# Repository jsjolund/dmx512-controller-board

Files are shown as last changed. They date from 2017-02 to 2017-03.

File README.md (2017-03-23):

# Sunshine DMX512 Controller Board
Controller board for DMX512 compatible lighting fixtures, built around the ARM Cortex-M4 processor (STM32F411RET).

On the hardware side, there are of four PCB:s, a main board containing the microcontroller as well as DMX512, USB USART and power circuitry. Other boards contain buttons, LCD, potentiometer sliders and similar. See the Kicad project files for details.

The software is built using the STM32 hardware abstraction layer (HAL). Aside from hardware drivers for the various input devices, it contains DMX512 generation and a simple menu system for the LCD.

Enclosure

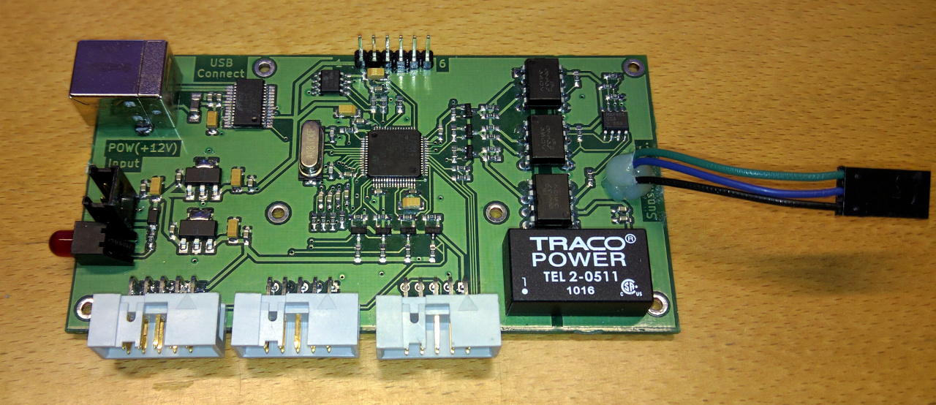
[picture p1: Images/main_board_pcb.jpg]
Main PCB


## STM32F411 docs
[Nucleo-64 board documentation](http://www.st.com/web/en/resource/technical/document/user_manual/DM00105823.pdf)

[STM32F411 Datasheet](http://www.st.com/resource/en/datasheet/stm32f411re.pdf)

[STM32F411 Reference Manual](http://www.st.com/resource/en/reference_manual/dm00119316.pdf)

[STM32F411 Programming Manual](http://www.st.com/resource/en/programming_manual/dm00046982.pdf)

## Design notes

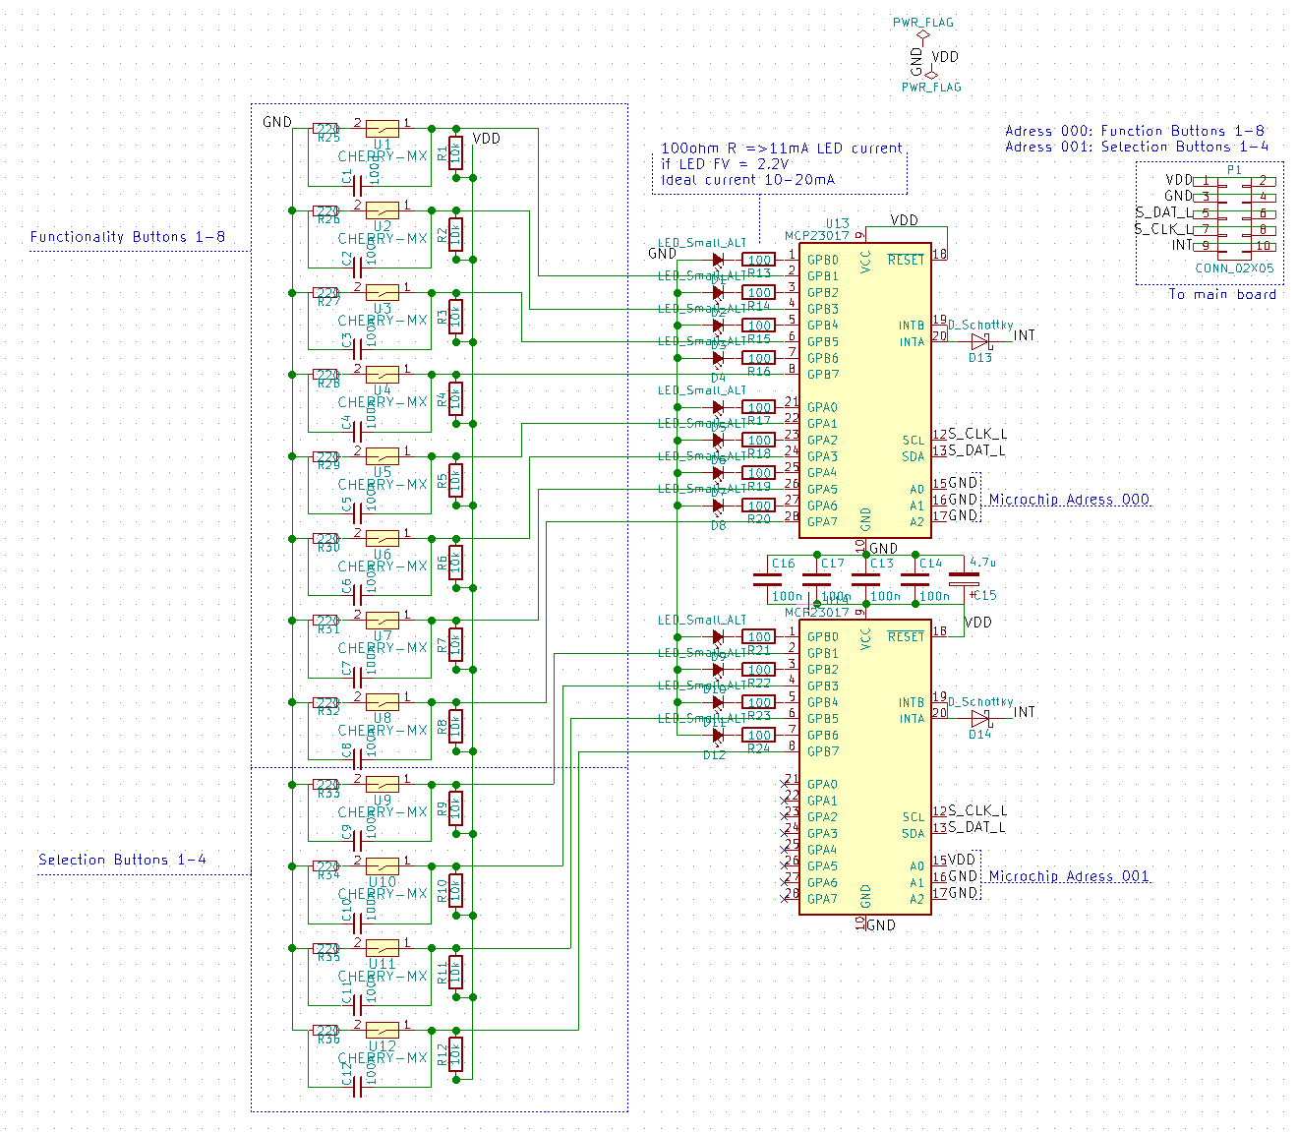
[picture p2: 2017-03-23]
Images/kicad_schematic_buttons.png

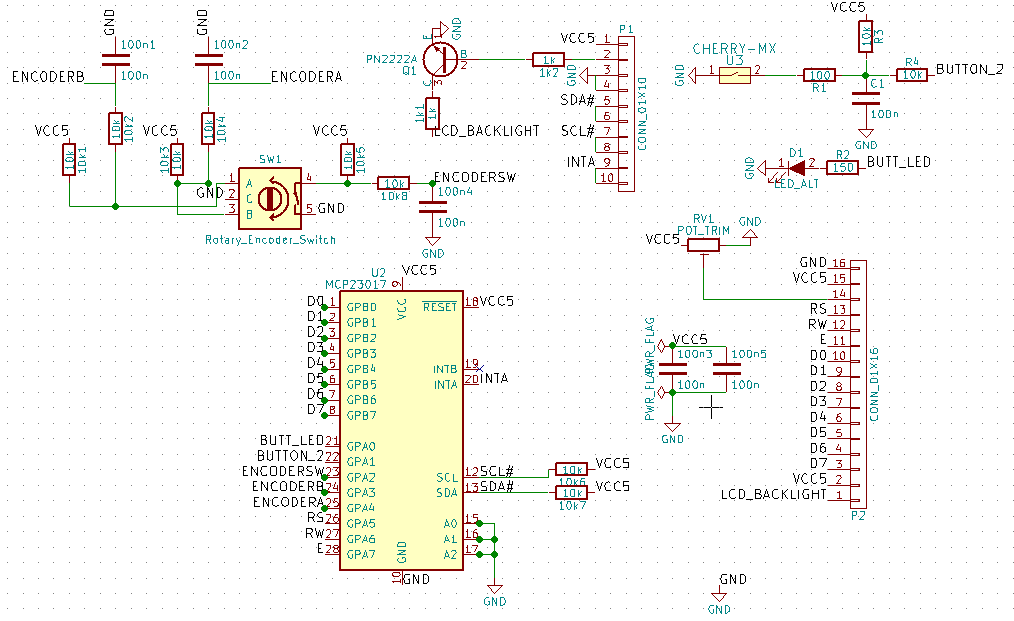
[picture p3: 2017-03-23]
Images/kicad_schematic_lcd.png

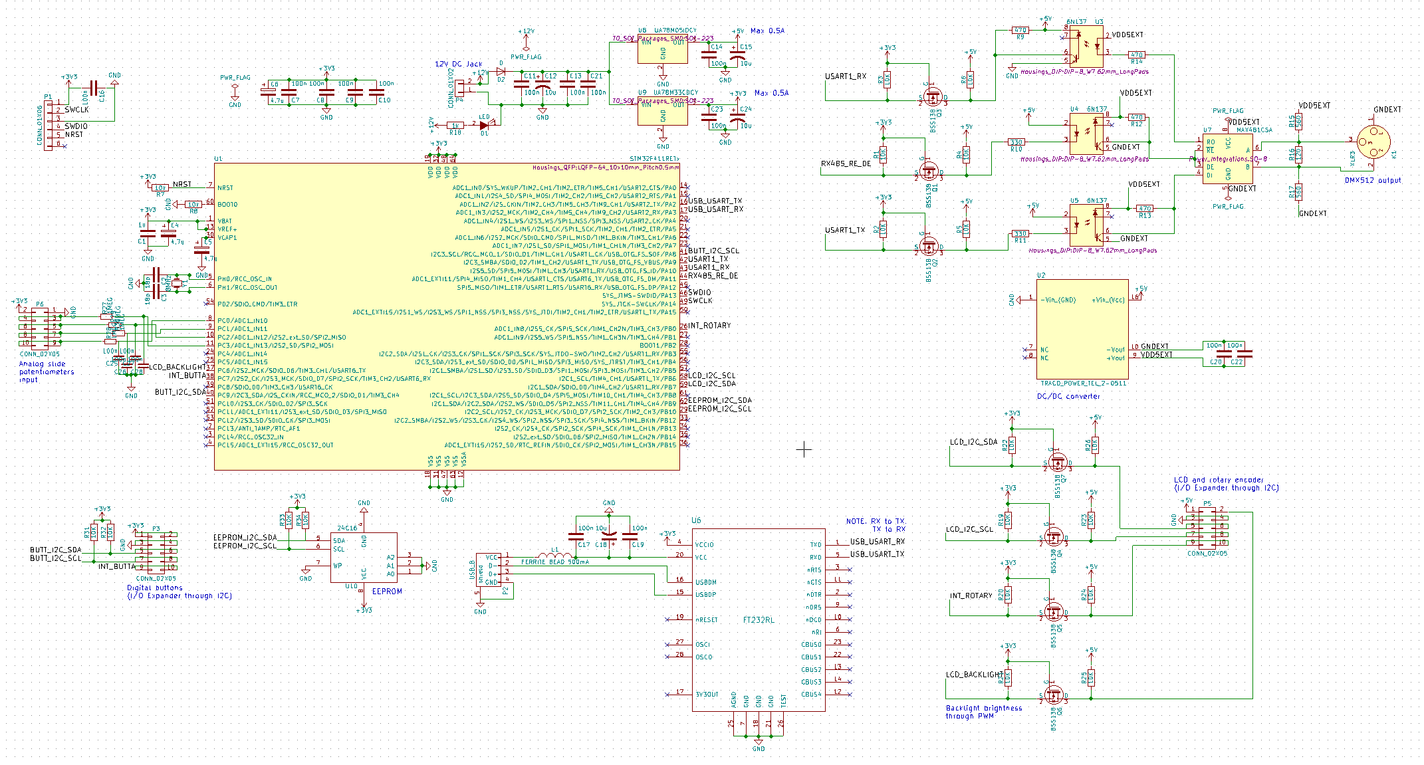
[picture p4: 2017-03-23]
Images/kicad_schematic_main.png

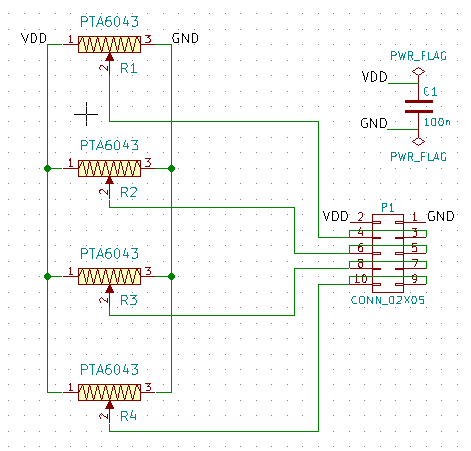
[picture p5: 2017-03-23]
Images/kicad_schematic_sliders.png

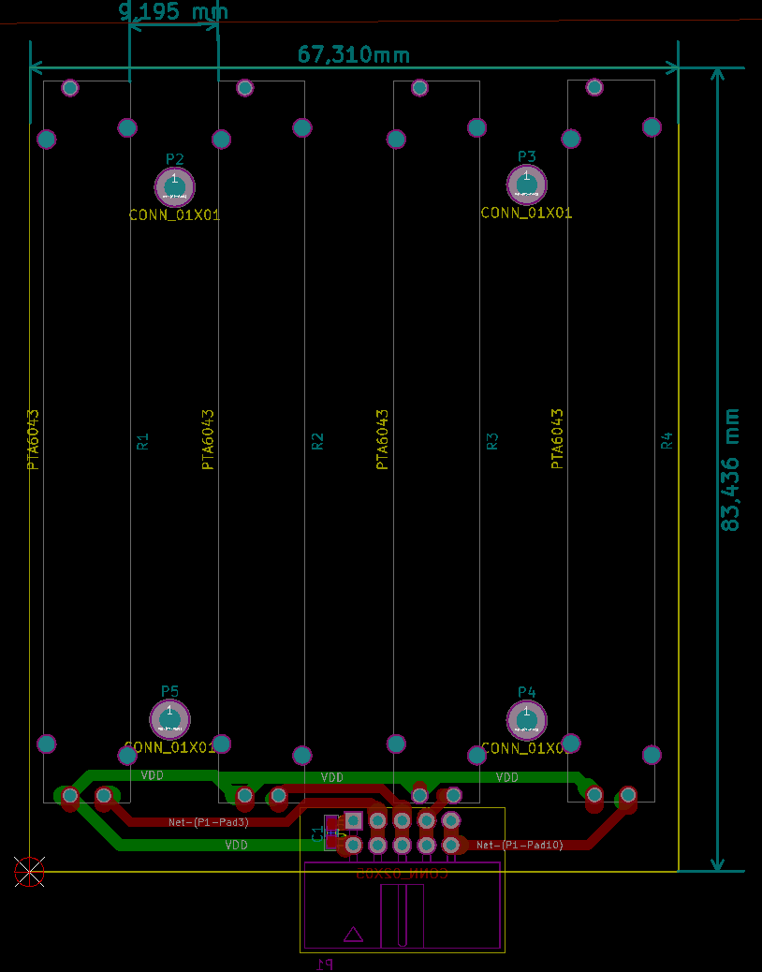
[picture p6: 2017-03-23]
Images/kicad_pcb_sliders.png

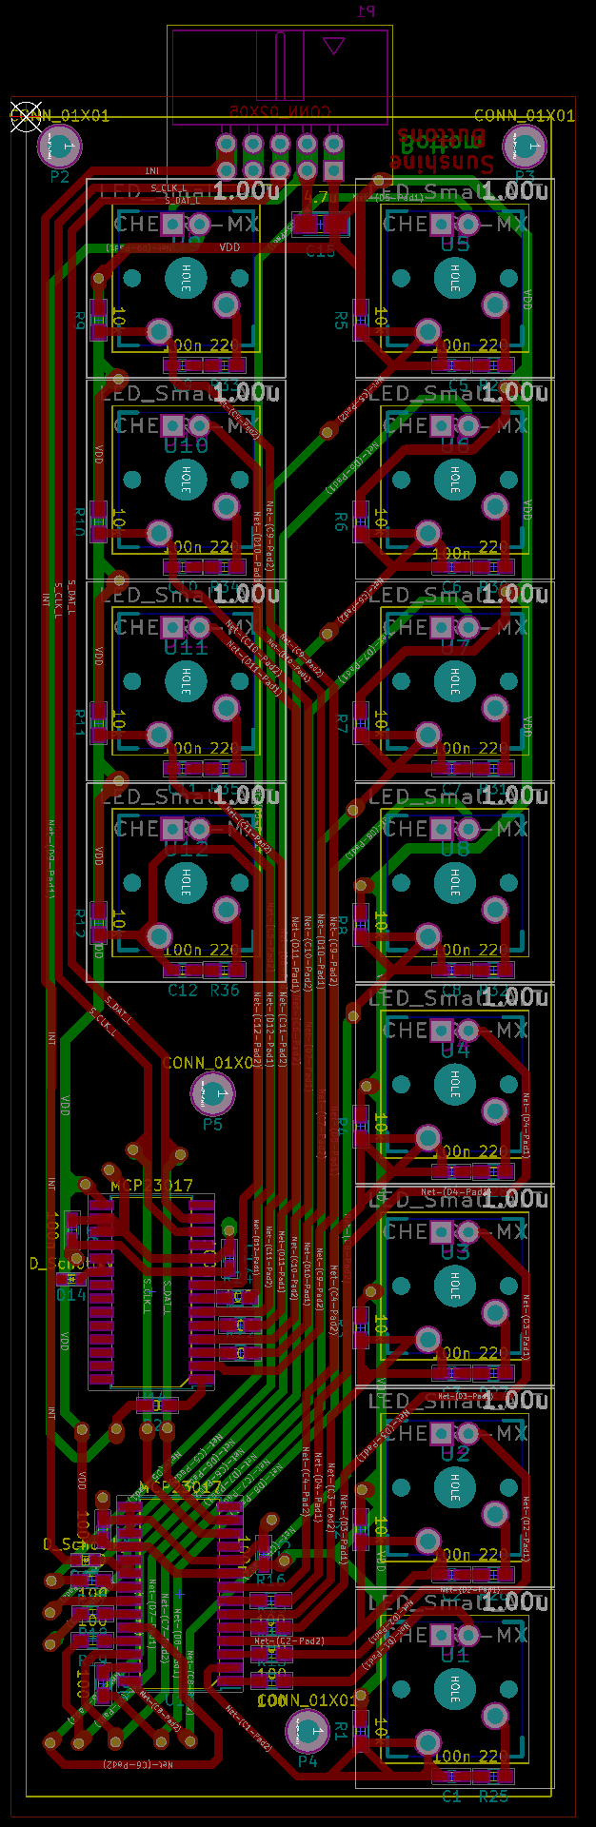
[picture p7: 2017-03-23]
Images/kicad_pcb_buttons.png

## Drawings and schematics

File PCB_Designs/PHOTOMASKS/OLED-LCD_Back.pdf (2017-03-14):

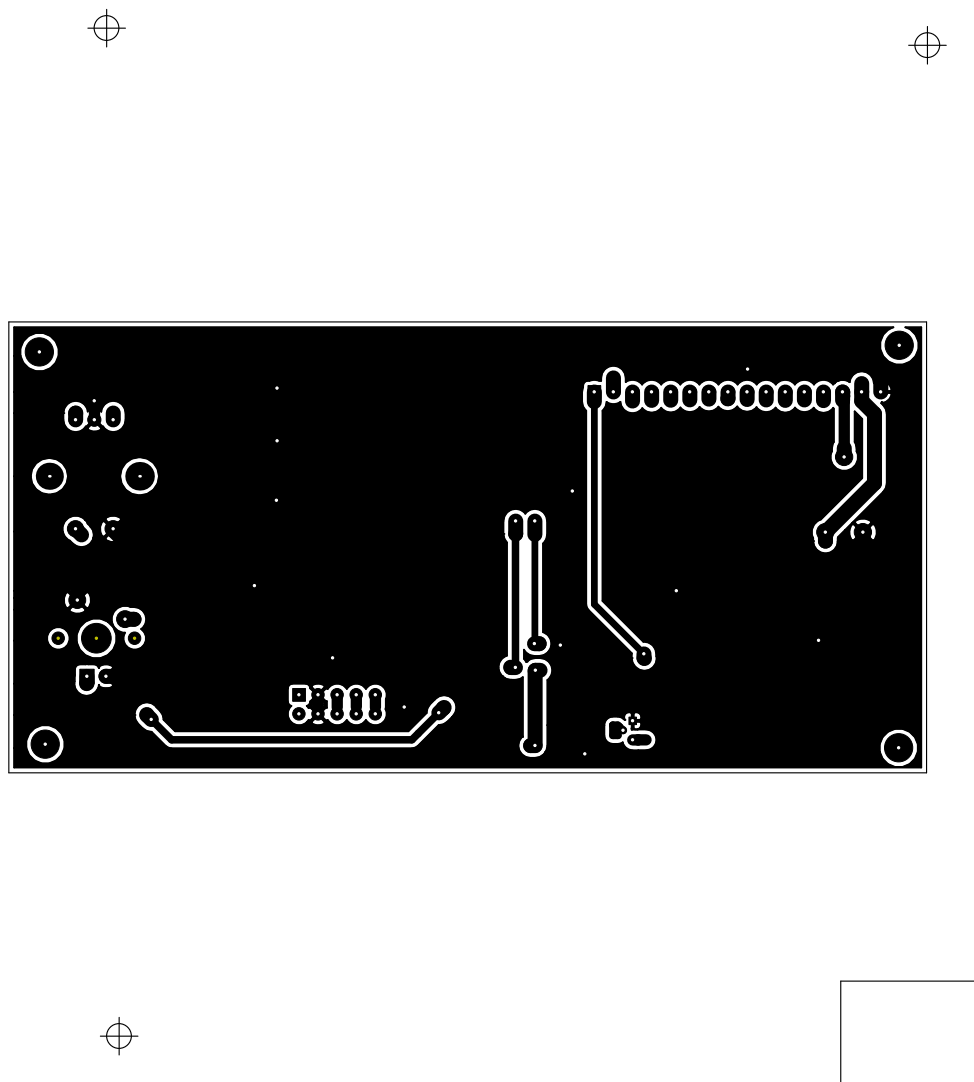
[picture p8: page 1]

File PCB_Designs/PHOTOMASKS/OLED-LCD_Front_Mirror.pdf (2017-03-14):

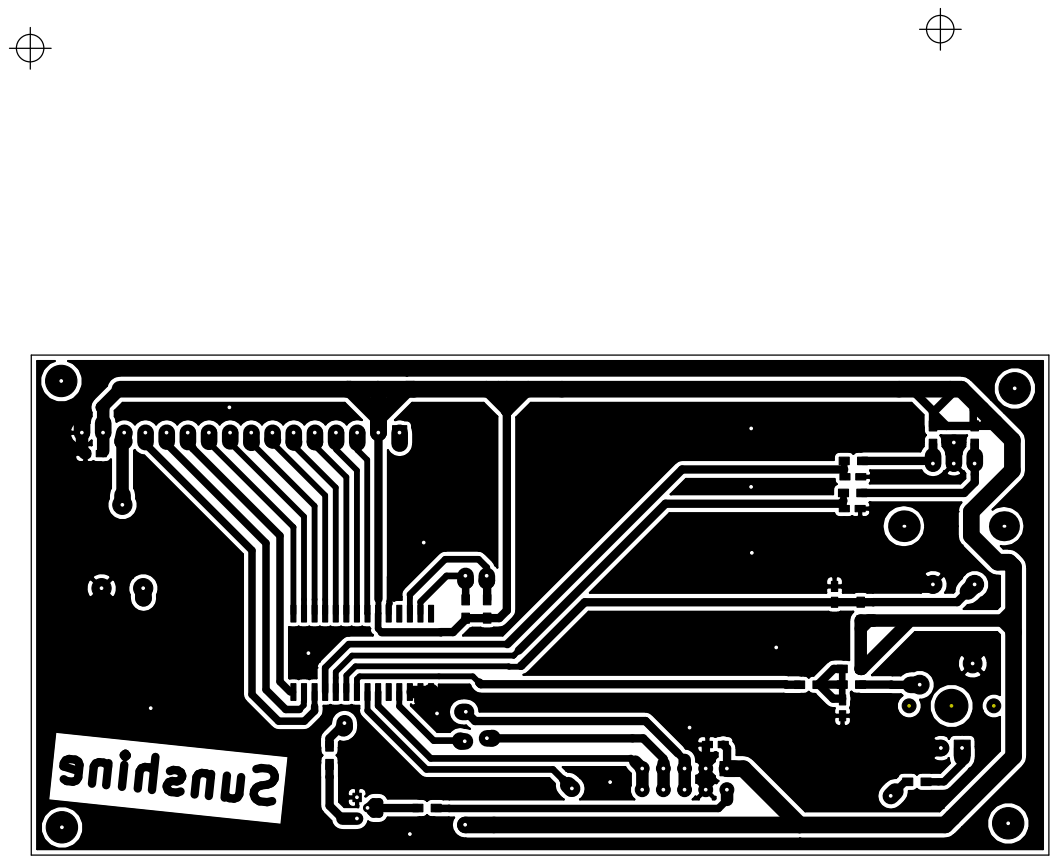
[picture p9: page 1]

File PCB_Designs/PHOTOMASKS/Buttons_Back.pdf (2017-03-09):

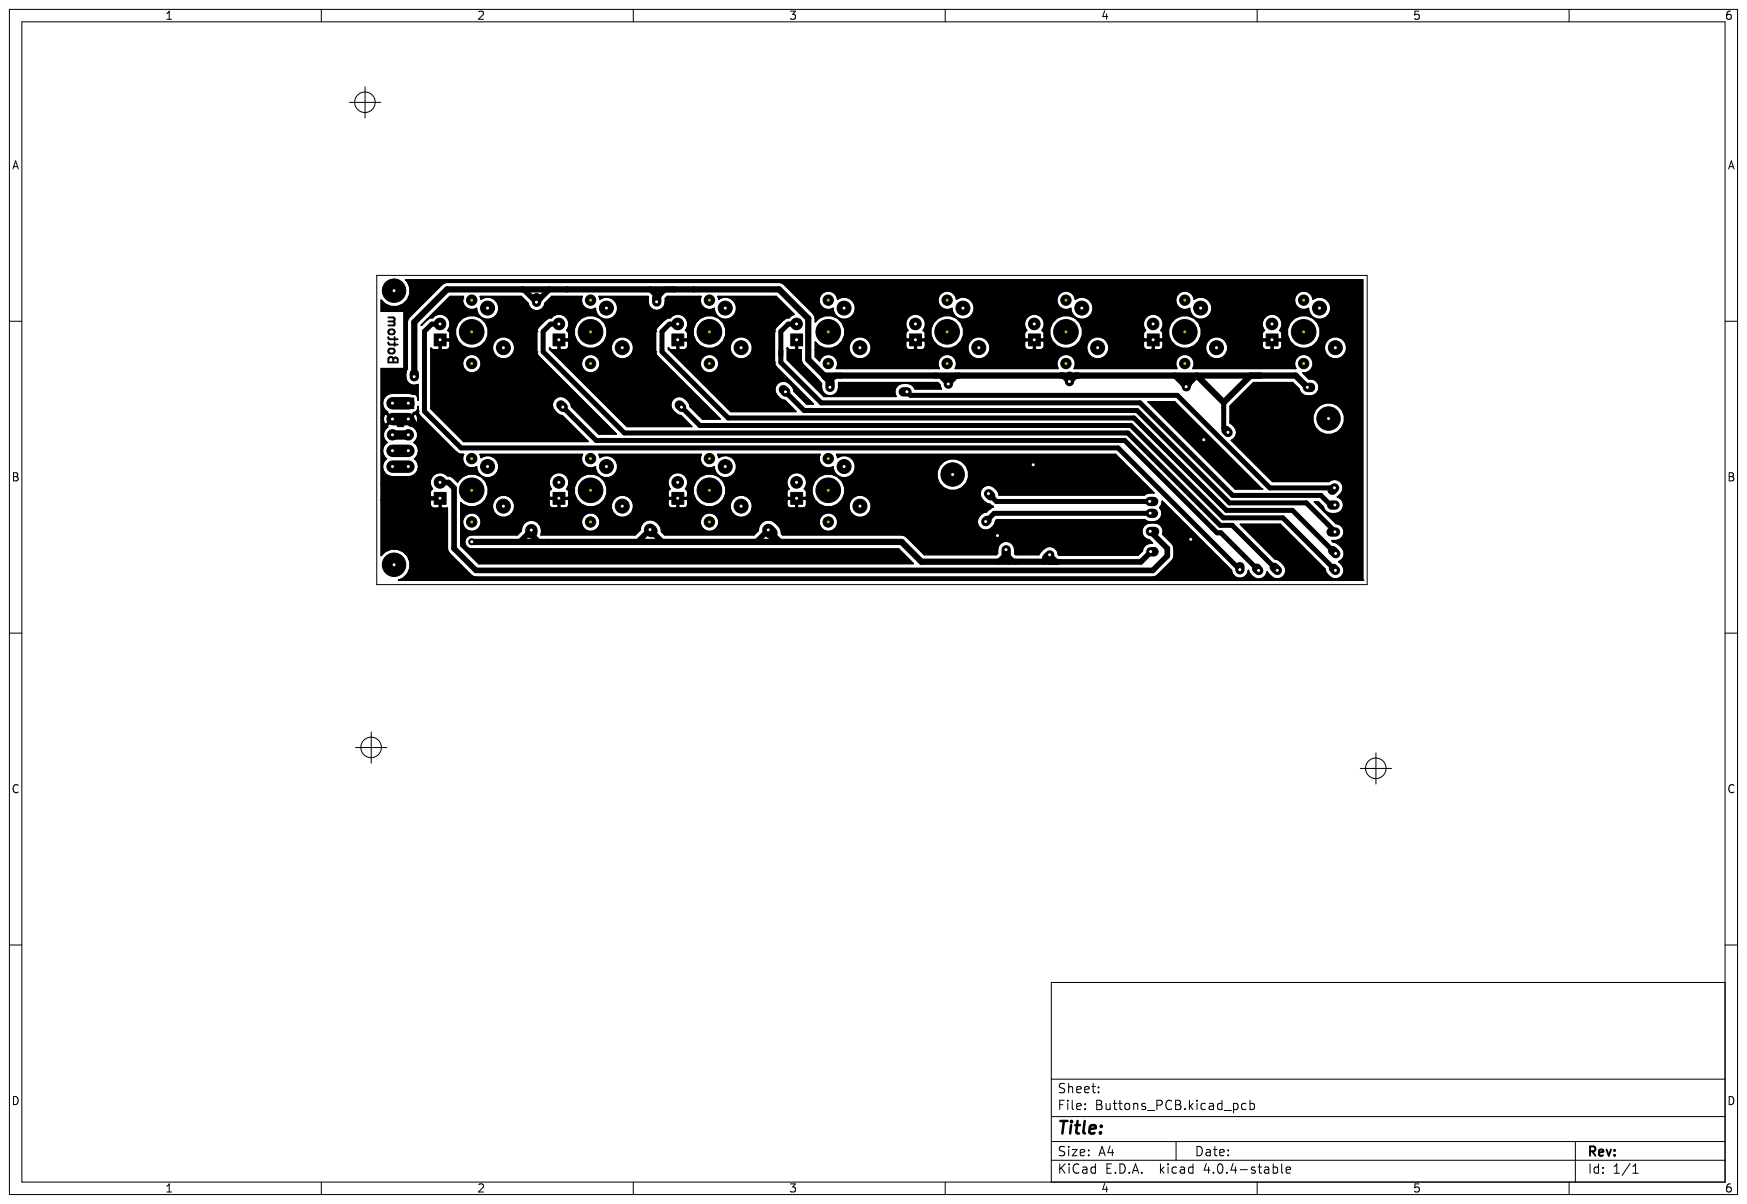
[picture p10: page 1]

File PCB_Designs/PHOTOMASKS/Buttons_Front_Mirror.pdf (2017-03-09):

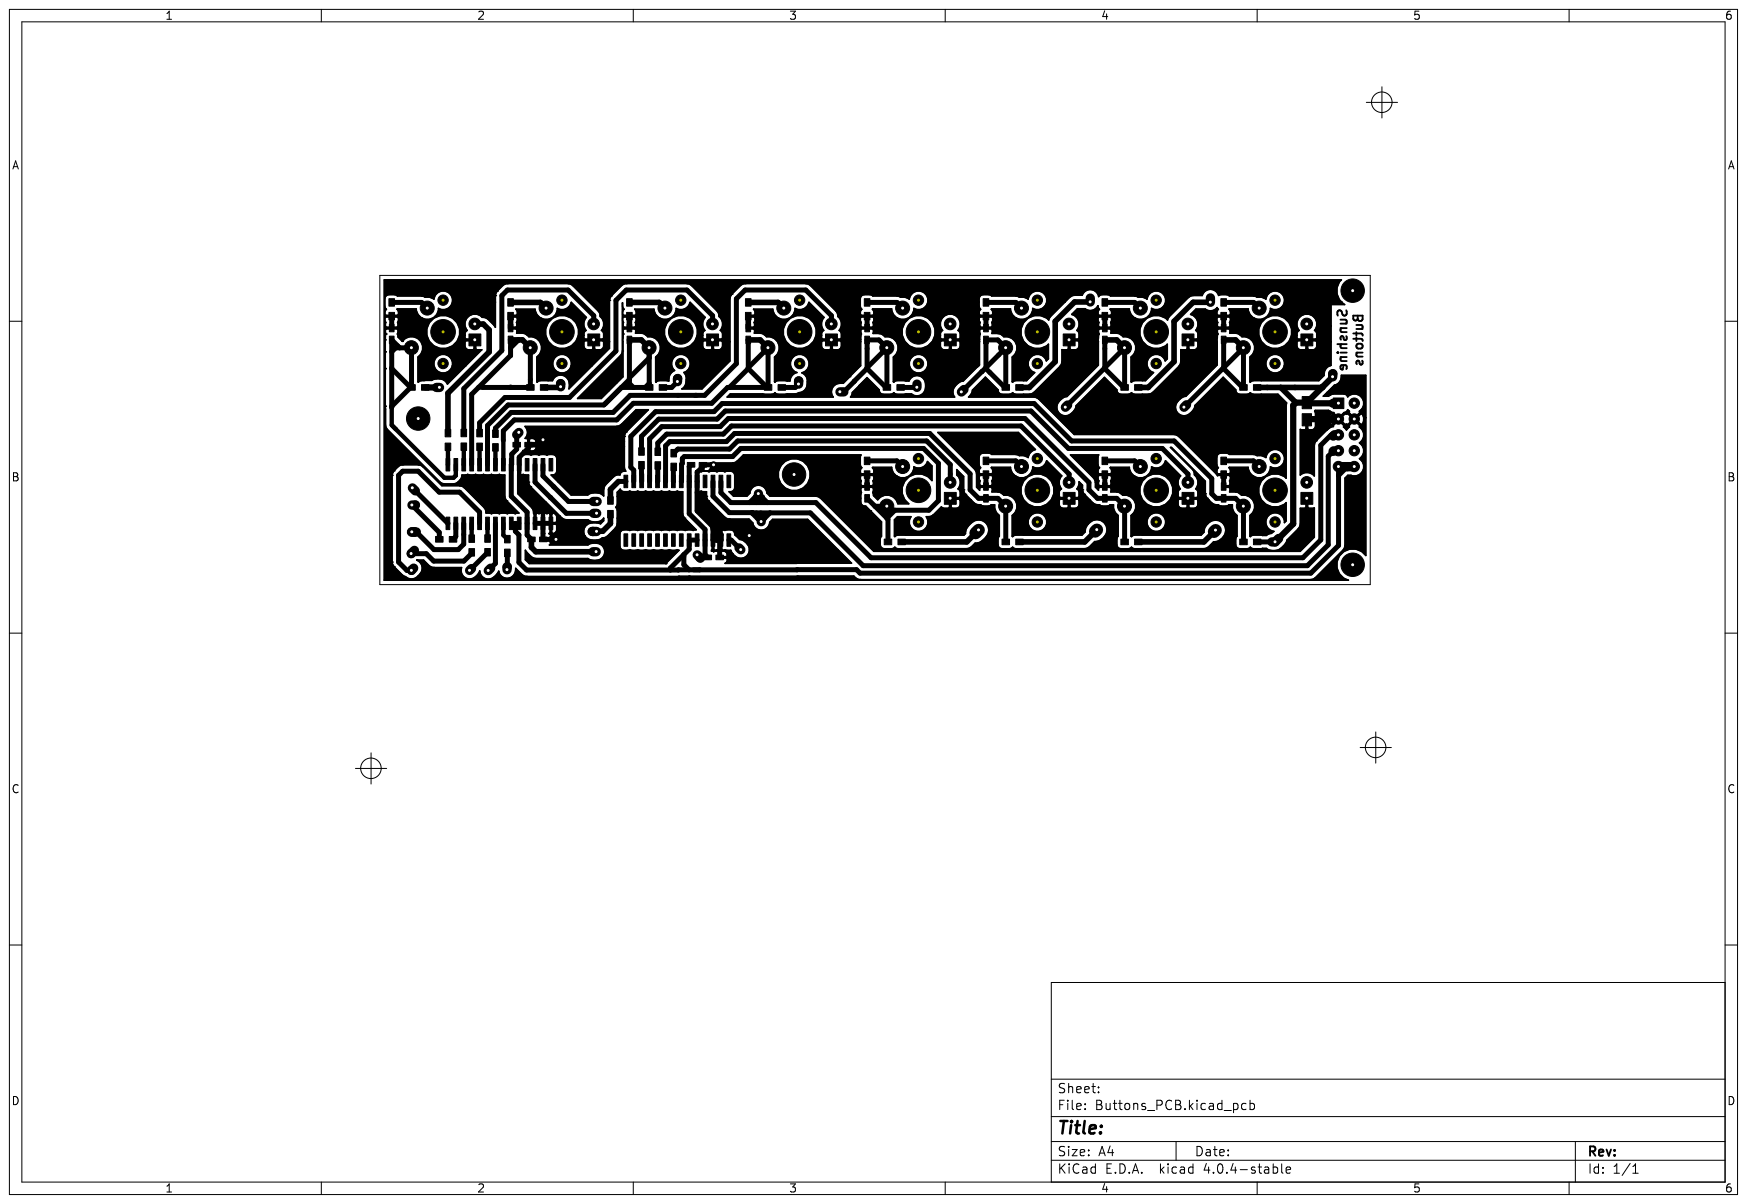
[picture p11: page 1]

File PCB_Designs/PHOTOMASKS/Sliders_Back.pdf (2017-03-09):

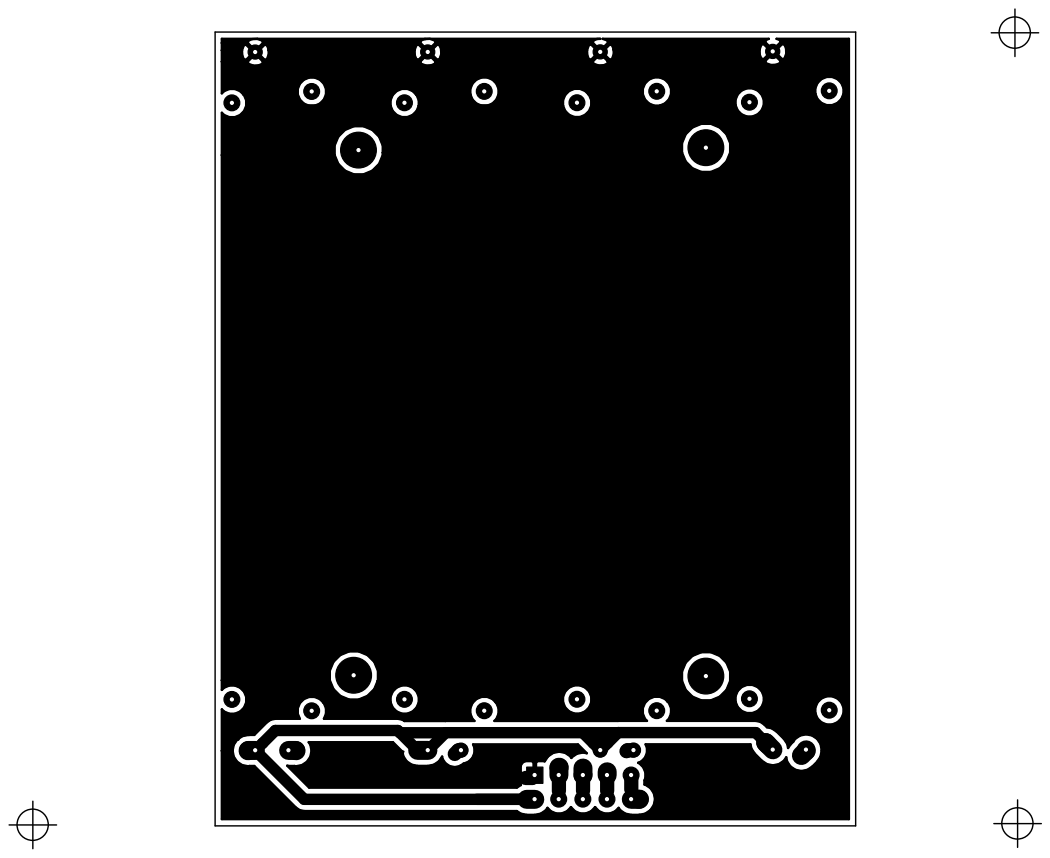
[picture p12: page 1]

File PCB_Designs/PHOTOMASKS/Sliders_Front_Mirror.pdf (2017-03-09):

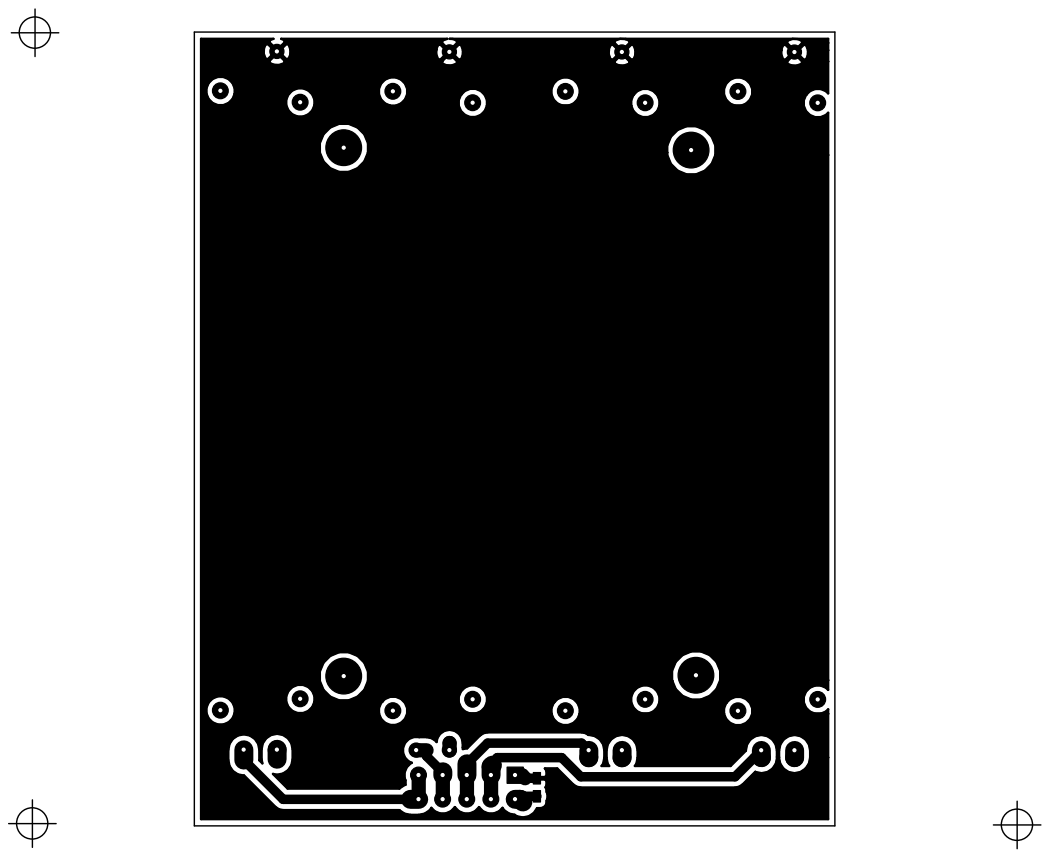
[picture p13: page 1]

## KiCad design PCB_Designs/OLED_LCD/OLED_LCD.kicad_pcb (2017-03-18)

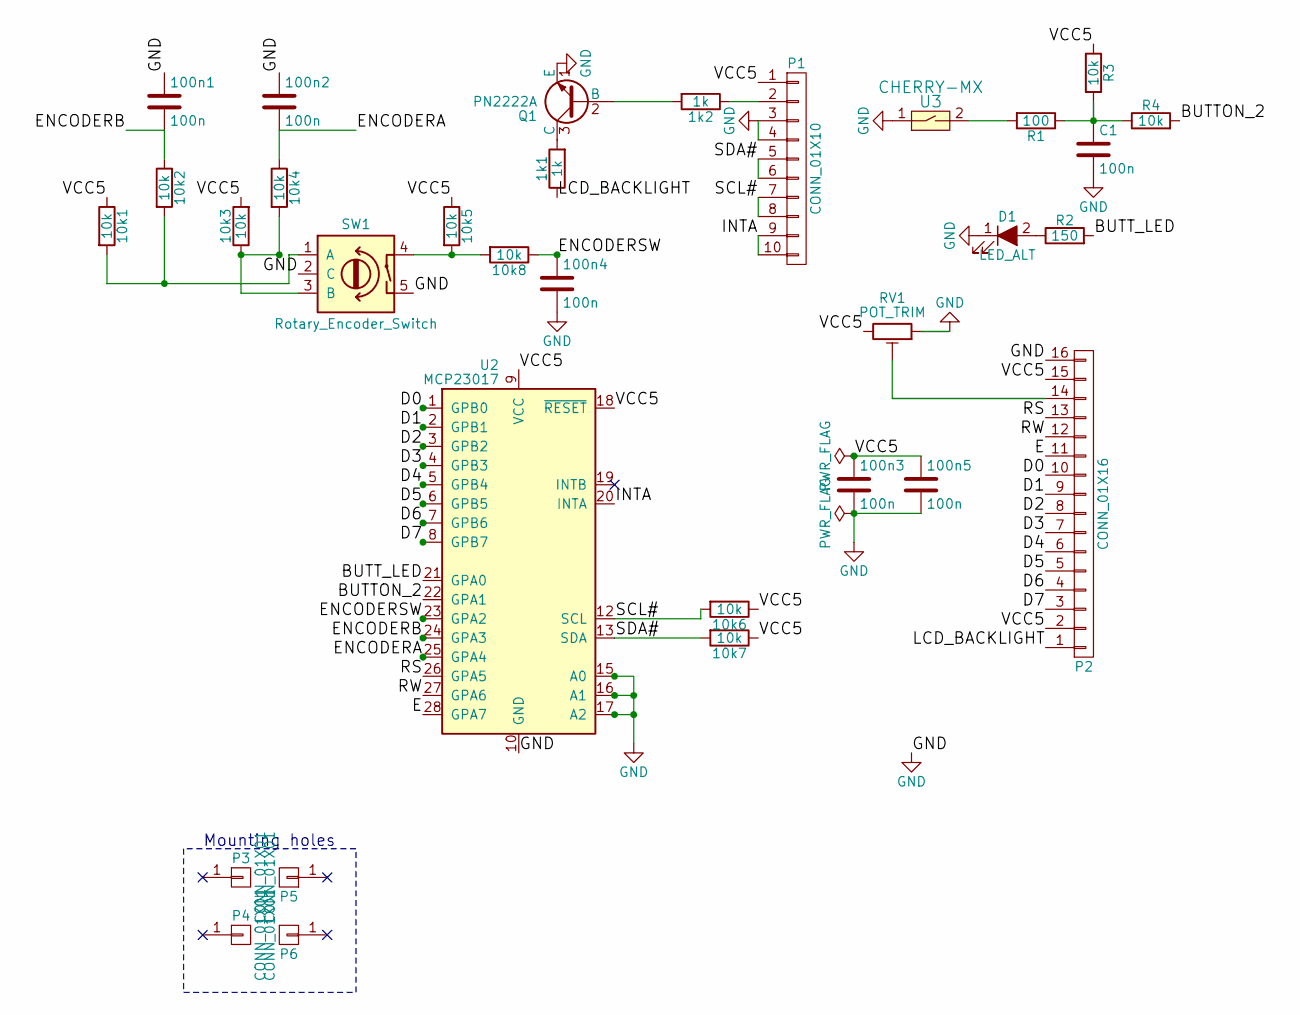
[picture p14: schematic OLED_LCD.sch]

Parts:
1k1, 1k2: 1k; R_0603_HandSoldering
10k1, 10k2, 10k3, 10k4, 10k5, 10k6, 10k7, 10k8: 10k; R_0603_HandSoldering
100n1, 100n2, 100n3, 100n4, 100n5: 100n; C_0603_HandSoldering
C1: 100n; C_0603_HandSoldering
D1: LED_ALT; CHERRY_MX_LED
P1: CONN_01X10; Multicomp_MC9A22-1034_2x05x2.54mm_Angled
P2: CONN_01X16; Pin_Header_Straight_1x16_Pitch2.54mm
P3, P4, P5, P6: CONN_01X01; MountingHole_2.2mm_M2_DIN965_Pad
Q1: PN2222A; TO-92_Molded_Narrow
R1: 100; R_0603_HandSoldering
R2: 150; R_0603_HandSoldering
R3, R4: 10k; R_0603_HandSoldering
RV1: POT_TRIM; Potentiometer_Trimmer_ACP_CA9v_Horizontal_Px10.0mm_Py5.0mm
SW1: Rotary_Encoder_Switch; Rotary_encoder
U2: MCP23017; SOIC-28W_7.5x17.9mm_Pitch1.27mm
U3: CHERRY-MX; CHERRY_PCB_100H

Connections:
/BUTTON_2: R4.2, U2.22 (GPA1)
/BUTT_LED: R2.2, U2.21 (GPA0)
/D0: P2.10, U2.1 (GPB0)
/D1: P2.9, U2.2 (GPB1)
/D2: P2.8, U2.3 (GPB2)
/D3: P2.7, U2.4 (GPB3)
/D4: P2.6, U2.5 (GPB4)
/D5: P2.5, U2.6 (GPB5)
/D6: P2.4, U2.7 (GPB6)
/D7: P2.3, U2.8 (GPB7)
/E: P2.11, U2.28 (GPA7)
/ENCODERA: 10k4.1, 100n2.2, U2.25 (GPA4)
/ENCODERB: 10k2.1, 100n1.2, U2.24 (GPA3)
/ENCODERSW: 10k8.1, 100n4.1, U2.23 (GPA2)
/INTA: P1.9, P1.10, U2.20 (INTA)
/LCD_BACKLIGHT: 1k1.1, P2.1
/RS: P2.13, U2.26 (GPA5)
/RW: P2.12, U2.27 (GPA6)
/SCL#: 10k6.2, P1.7, P1.8, U2.12 (SCL)
/SDA#: 10k7.2, P1.5, P1.6, U2.13 (SDA)
/VCC5: 10k1.1, 10k3.2, 10k5.1, 10k6.1, 10k7.1, 100n3.1, 100n5.1, P1.1, P2.2, P2.15, R3.1, RV1.3, U2.9 (VCC), U2.18 (~RESET)
GND: 100n1.1, 100n2.1, 100n3.2, 100n4.2, 100n5.2, C1.2, D1.1 (K), P1.3, P1.4, P2.16, Q1.1 (E), RV1.1, SW1.2 (C), SW1.5, U2.10 (GND), U2.15 (A0), U2.16 (A1), U2.17 (A2), U3.1
unnamed: 1k1.2, Q1.3 (C)
unnamed: 1k2.1, P1.2
unnamed: 1k2.2, Q1.2 (B)
unnamed: 10k1.2, 10k2.2, SW1.1 (A)
unnamed: 10k3.1, 10k4.2, SW1.3 (B)
unnamed: 10k5.2, 10k8.2, SW1.4
unnamed: C1.1, R1.1, R3.2, R4.1
unnamed: D1.2 (A), R2.1
unnamed: P2.14, RV1.2
unnamed: R1.2, U3.2

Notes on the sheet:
Mounting holes

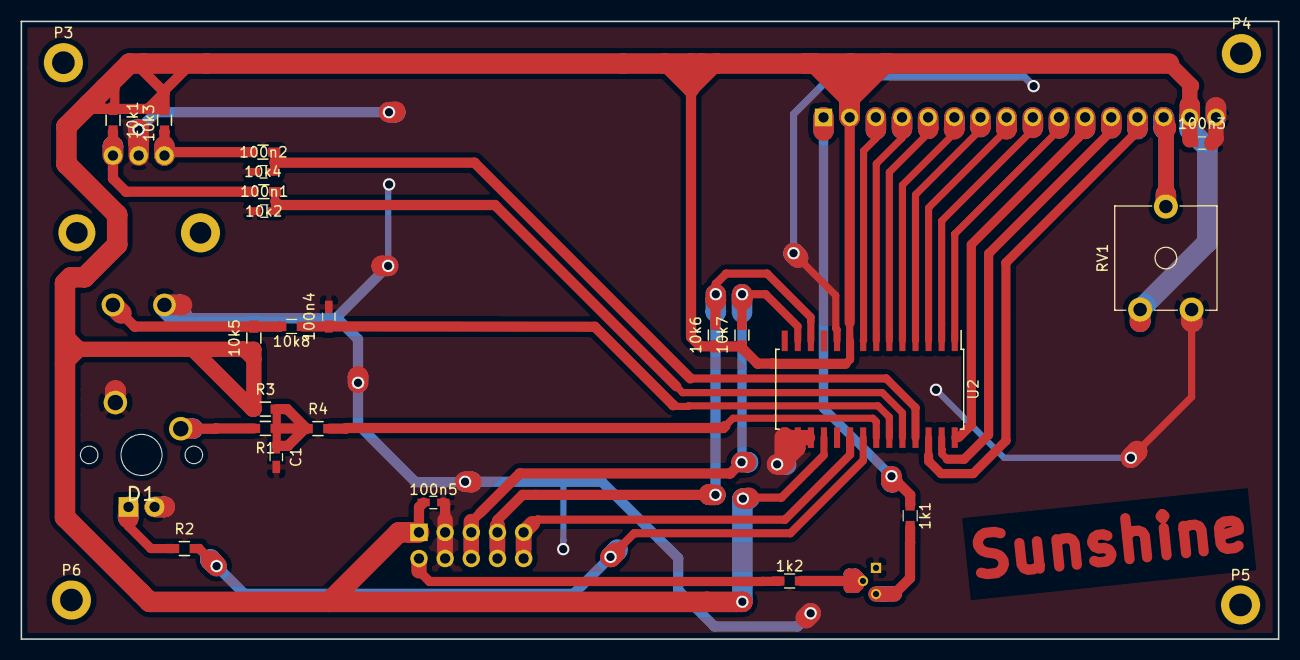
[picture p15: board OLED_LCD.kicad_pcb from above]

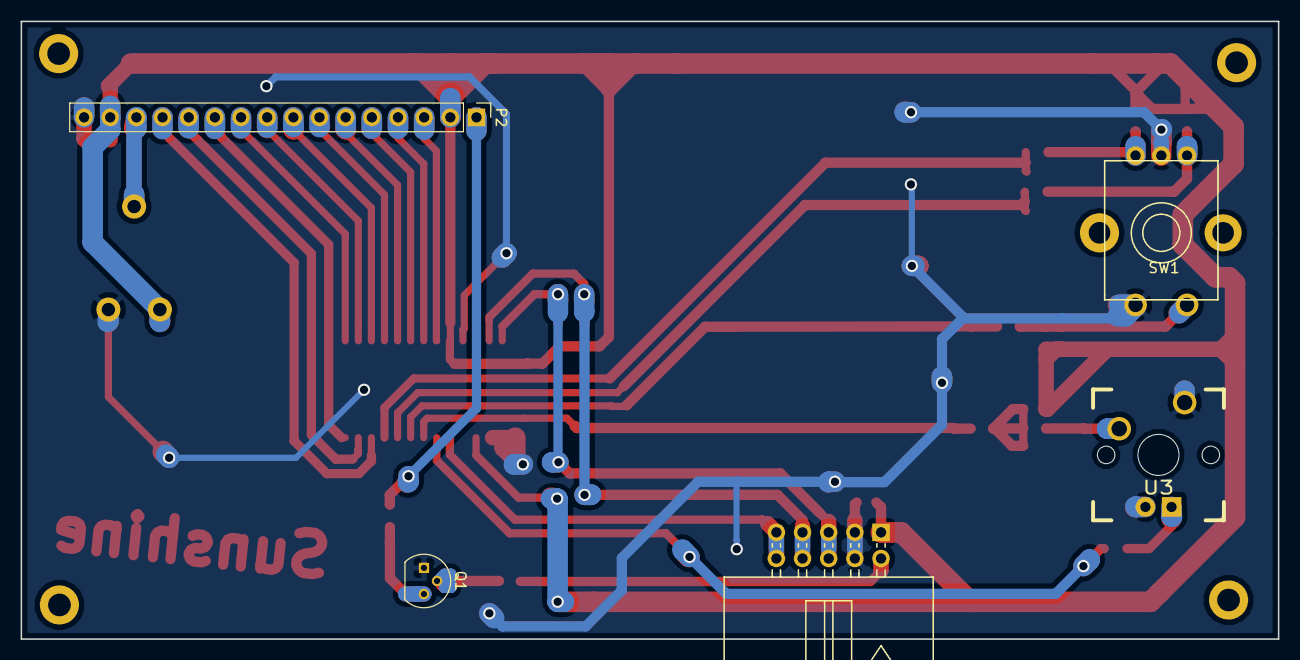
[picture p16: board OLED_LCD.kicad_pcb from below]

Board: 2 copper layers, 122.1 x 60.0 mm, 32 parts (6 on the bottom side), 32 nets.

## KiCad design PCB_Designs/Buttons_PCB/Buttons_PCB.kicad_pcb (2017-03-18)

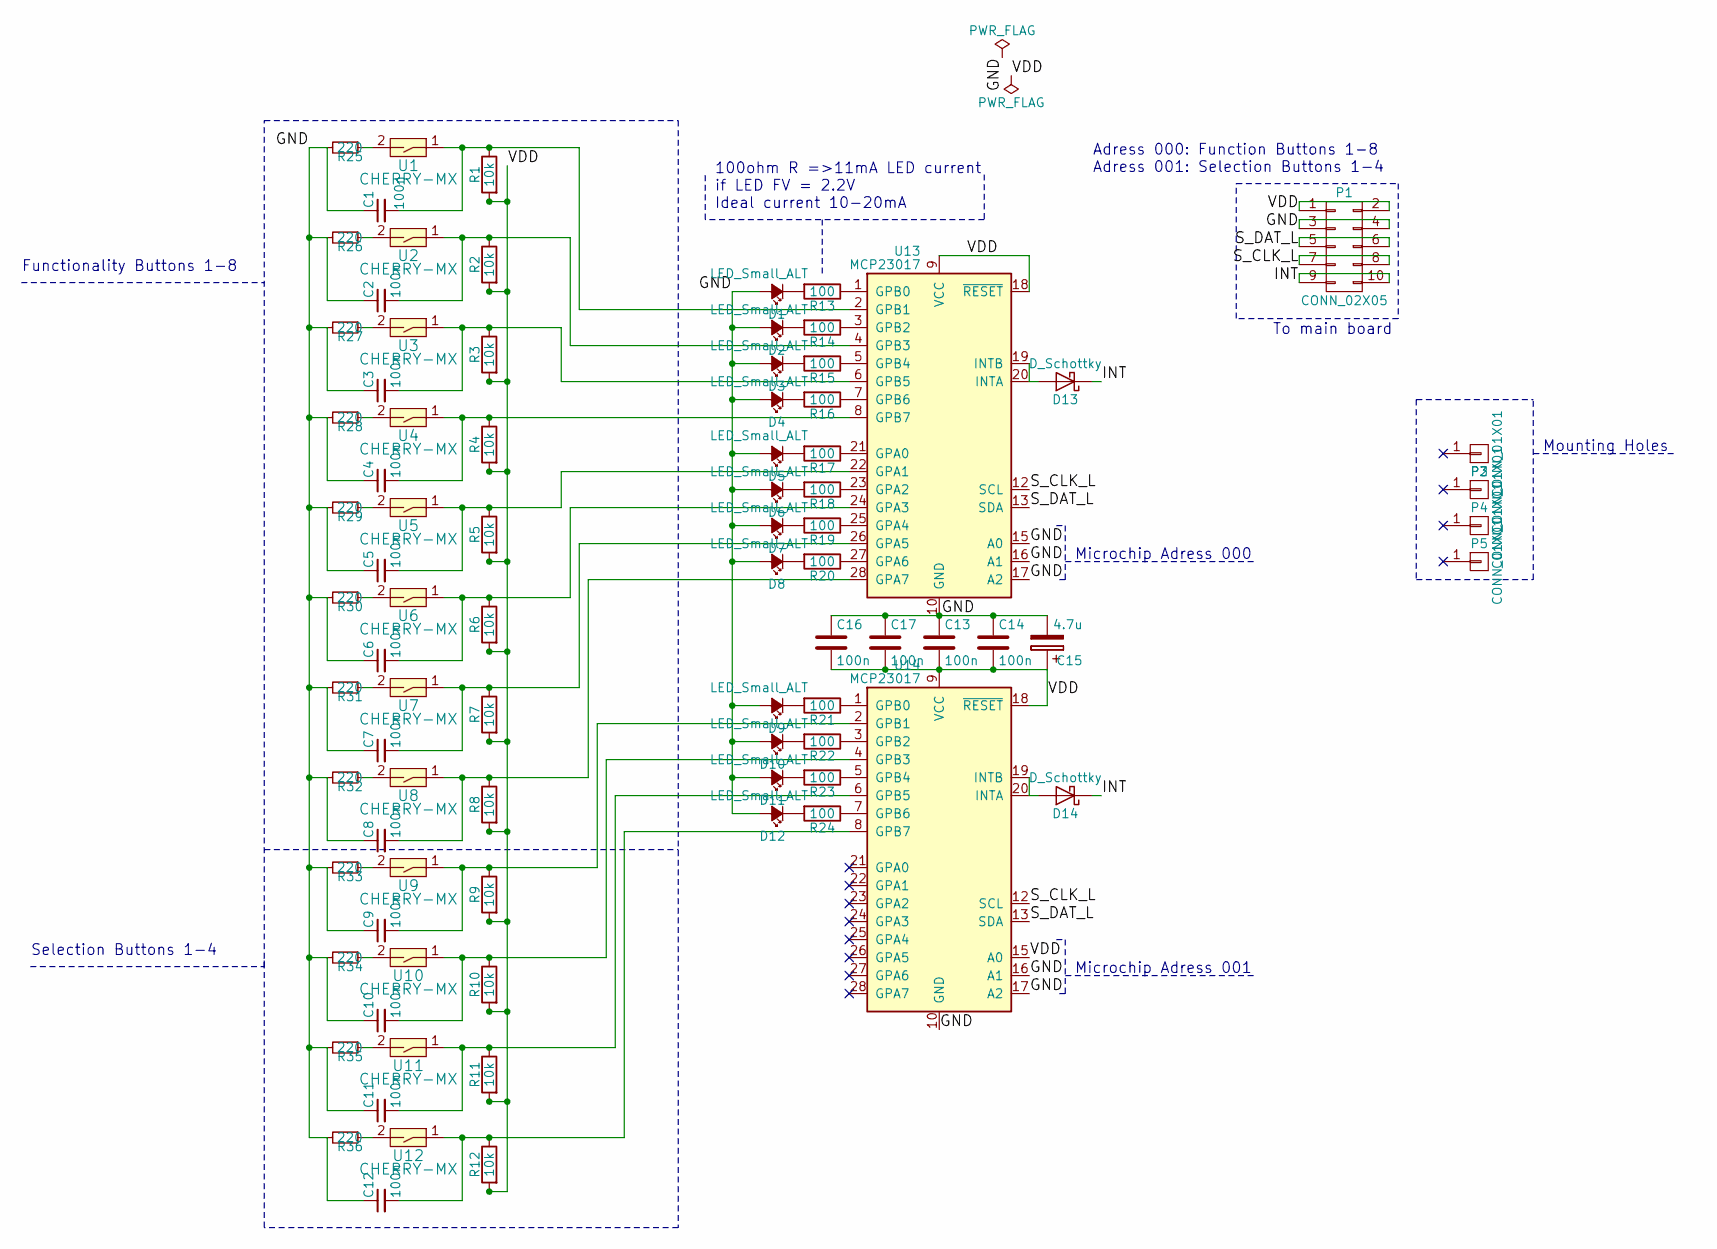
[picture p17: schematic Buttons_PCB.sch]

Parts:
C1, C2, C3, C4, C5, C6, C7, C8, C9, C10, C11, C12, C13, C14, C16, C17: 100n; C_0603_HandSoldering
C15: 4.7u; CP_Tantalum_Case-A_EIA-3216-18_Reflow
D1, D2, D3, D4, D5, D6, D7, D8, D9, D10, D11, D12: LED_Small_ALT; CHERRY_MX_LED
D13, D14: D_Schottky; D_0603
P1: CONN_02X05; Multicomp_MC9A22-1034_2x05x2.54mm_Angled
P2, P3, P4, P5: CONN_01X01; MountingHole_2.2mm_M2_DIN965_Pad
R1, R2, R3, R4, R5, R6, R7, R8, R9, R10, R11, R12: 10k; R_0603_HandSoldering
R13, R14, R15, R16, R17, R18, R19, R20, R21, R22, R23, R24: 100; R_0603_HandSoldering
R25, R26, R27, R28, R29, R30, R31, R32, R33, R34, R35, R36: 220; R_0603_HandSoldering
U1, U2, U3, U4, U5, U6, U7, U8, U9, U10, U11, U12: CHERRY-MX; CHERRY_PCB_100H
U13, U14: MCP23017; SOIC-28W_7.5x17.9mm_Pitch1.27mm

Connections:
/GND: C1.1, C2.1, C3.1, C4.1, C5.1, C6.1, C7.1, C8.1, C9.1, C10.1, C11.1, C12.1, C13.1, C14.1, C15.2, C16.1, C17.1, D1.2 (A), D2.2 (A), D3.2 (A), D4.2 (A), D5.2 (A), D6.2 (A), D7.2 (A), D8.2 (A), D9.2 (A), D10.2 (A), D11.2 (A), D12.2 (A), P1.3, P1.4, R25.2, R26.2, R27.2, R28.2, R29.2, R30.2, R31.2, R32.2, R33.2, R34.2, R35.2, R36.2, U13.10 (GND), U13.15 (A0), U13.16 (A1), U13.17 (A2), U14.10 (GND), U14.16 (A1), U14.17 (A2)
/INT: D13.1 (K), D14.1 (K), P1.9, P1.10
/S_CLK_L: P1.7, P1.8, U13.12 (SCL), U14.12 (SCL)
/S_DAT_L: P1.5, P1.6, U13.13 (SDA), U14.13 (SDA)
/VDD: C13.2, C14.2, C15.1, C16.2, C17.2, P1.1, P1.2, R1.2, R2.2, R3.2, R4.2, R5.2, R6.2, R7.2, R8.2, R9.2, R10.2, R11.2, R12.2, U13.9 (VCC), U13.18 (~RESET), U14.9 (VCC), U14.15 (A0), U14.18 (~RESET)
unnamed: C1.2, R1.1, U1.1, U13.2 (GPB1)
unnamed: C2.2, R2.1, U2.1, U13.4 (GPB3)
unnamed: C3.2, R3.1, U3.1, U13.6 (GPB5)
unnamed: C4.2, R4.1, U4.1, U13.8 (GPB7)
unnamed: C5.2, R5.1, U5.1, U13.22 (GPA1)
unnamed: C6.2, R6.1, U6.1, U13.24 (GPA3)
unnamed: C7.2, R7.1, U7.1, U13.26 (GPA5)
unnamed: C8.2, R8.1, U8.1, U13.28 (GPA7)
unnamed: C9.2, R9.1, U9.1, U14.2 (GPB1)
unnamed: C10.2, R10.1, U10.1, U14.4 (GPB3)
unnamed: C11.2, R11.1, U11.1, U14.6 (GPB5)
unnamed: C12.2, R12.1, U12.1, U14.8 (GPB7)
unnamed: D1.1 (K), R13.2
unnamed: D2.1 (K), R14.2
unnamed: D3.1 (K), R15.2
unnamed: D4.1 (K), R16.2
unnamed: D5.1 (K), R17.2
unnamed: D6.1 (K), R18.2
unnamed: D7.1 (K), R19.2
unnamed: D8.1 (K), R20.2
unnamed: D9.1 (K), R21.2
unnamed: D10.1 (K), R22.2
unnamed: D11.1 (K), R23.2
unnamed: D12.1 (K), R24.2
unnamed: D13.2 (A), U13.19 (INTB), U13.20 (INTA)
unnamed: D14.2 (A), U14.19 (INTB), U14.20 (INTA)
unnamed: R13.1, U13.1 (GPB0)
unnamed: R14.1, U13.3 (GPB2)
unnamed: R15.1, U13.5 (GPB4)
unnamed: R16.1, U13.7 (GPB6)
unnamed: R17.1, U13.21 (GPA0)
unnamed: R18.1, U13.23 (GPA2)
unnamed: R19.1, U13.25 (GPA4)
unnamed: R20.1, U13.27 (GPA6)
unnamed: R21.1, U14.1 (GPB0)
unnamed: R22.1, U14.3 (GPB2)
unnamed: R23.1, U14.5 (GPB4)
unnamed: R24.1, U14.7 (GPB6)
unnamed: R25.1, U1.2
unnamed: R26.1, U2.2
unnamed: R27.1, U3.2
unnamed: R28.1, U4.2
unnamed: R29.1, U5.2
unnamed: R30.1, U6.2
unnamed: R31.1, U7.2
unnamed: R32.1, U8.2
unnamed: R33.1, U9.2
unnamed: R34.1, U10.2
unnamed: R35.1, U11.2
unnamed: R36.1, U12.2

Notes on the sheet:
Microchip Adress 000
Microchip Adress 001
100ohm R =>11mA LED current if LED FV = 2.2V Ideal current 10-20mA
Functionality Buttons 1-8
Selection Buttons 1-4
Adress 000: Function Buttons 1-8 Adress 001: Selection Buttons 1-4
To main board
Mounting Holes

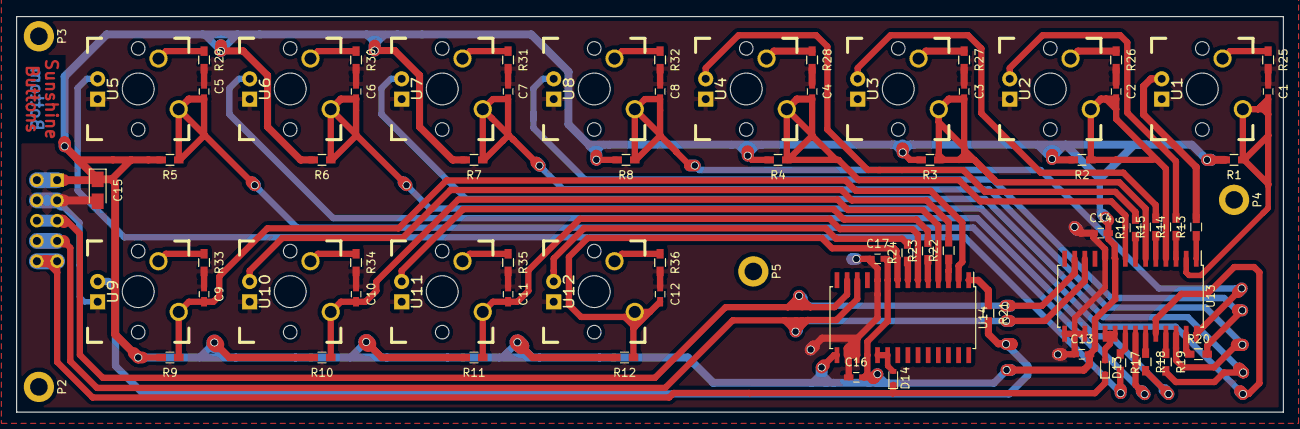
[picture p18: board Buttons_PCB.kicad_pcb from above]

Board: 2 copper layers, 158.8 x 49.6 mm, 86 parts (1 on the bottom side), 55 nets.

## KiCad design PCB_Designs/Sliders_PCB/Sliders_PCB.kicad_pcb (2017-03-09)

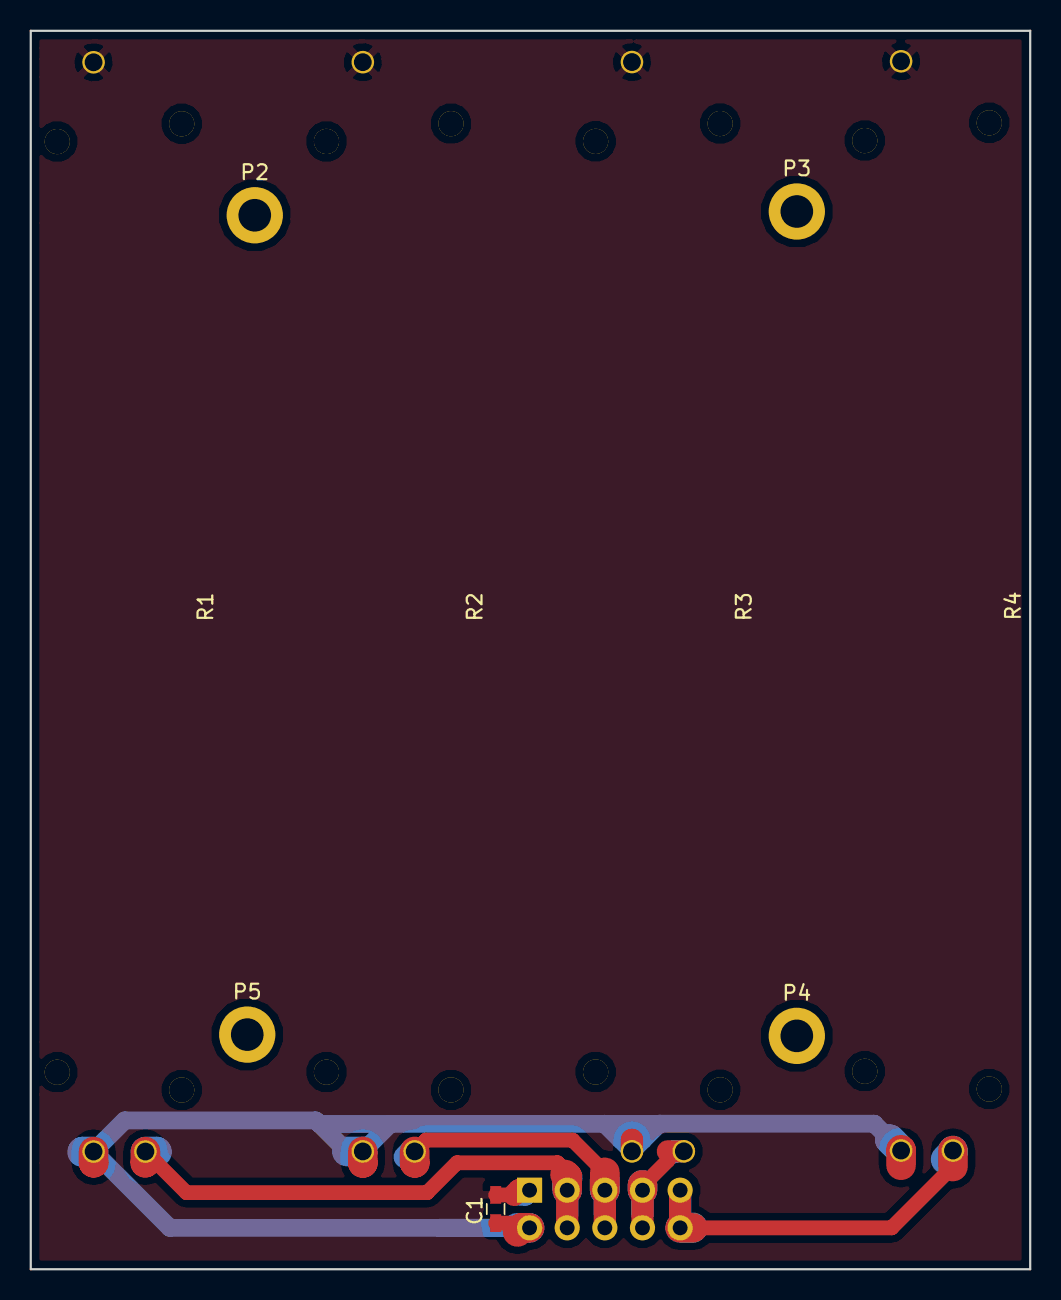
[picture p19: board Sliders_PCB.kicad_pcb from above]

Board: 2 copper layers, 67.4 x 83.6 mm, 10 parts (1 on the bottom side), 6 nets.

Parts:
C1: 100n; C_0603_HandSoldering
P1: CONN_02X05; Multicomp_MC9A22-1034_2x05x2.54mm_Angled
P2, P3, P4, P5: CONN_01X01; MountingHole_2.2mm_M2_DIN965_Pad
R1, R2, R3, R4: PTA6043; Potentiometer_Bourns-PTA6043

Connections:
/GND: C1.2, P1.1, R1.3, R2.3, R3.3, R4.3
/VDD: C1.1, P1.2, R1.1, R2.1, R3.1, R4.1
unnamed: P1.3, P1.4, R1.2
unnamed: P1.5, P1.6, R2.2
unnamed: P1.7, P1.8, R3.2
unnamed: P1.9, P1.10, R4.2

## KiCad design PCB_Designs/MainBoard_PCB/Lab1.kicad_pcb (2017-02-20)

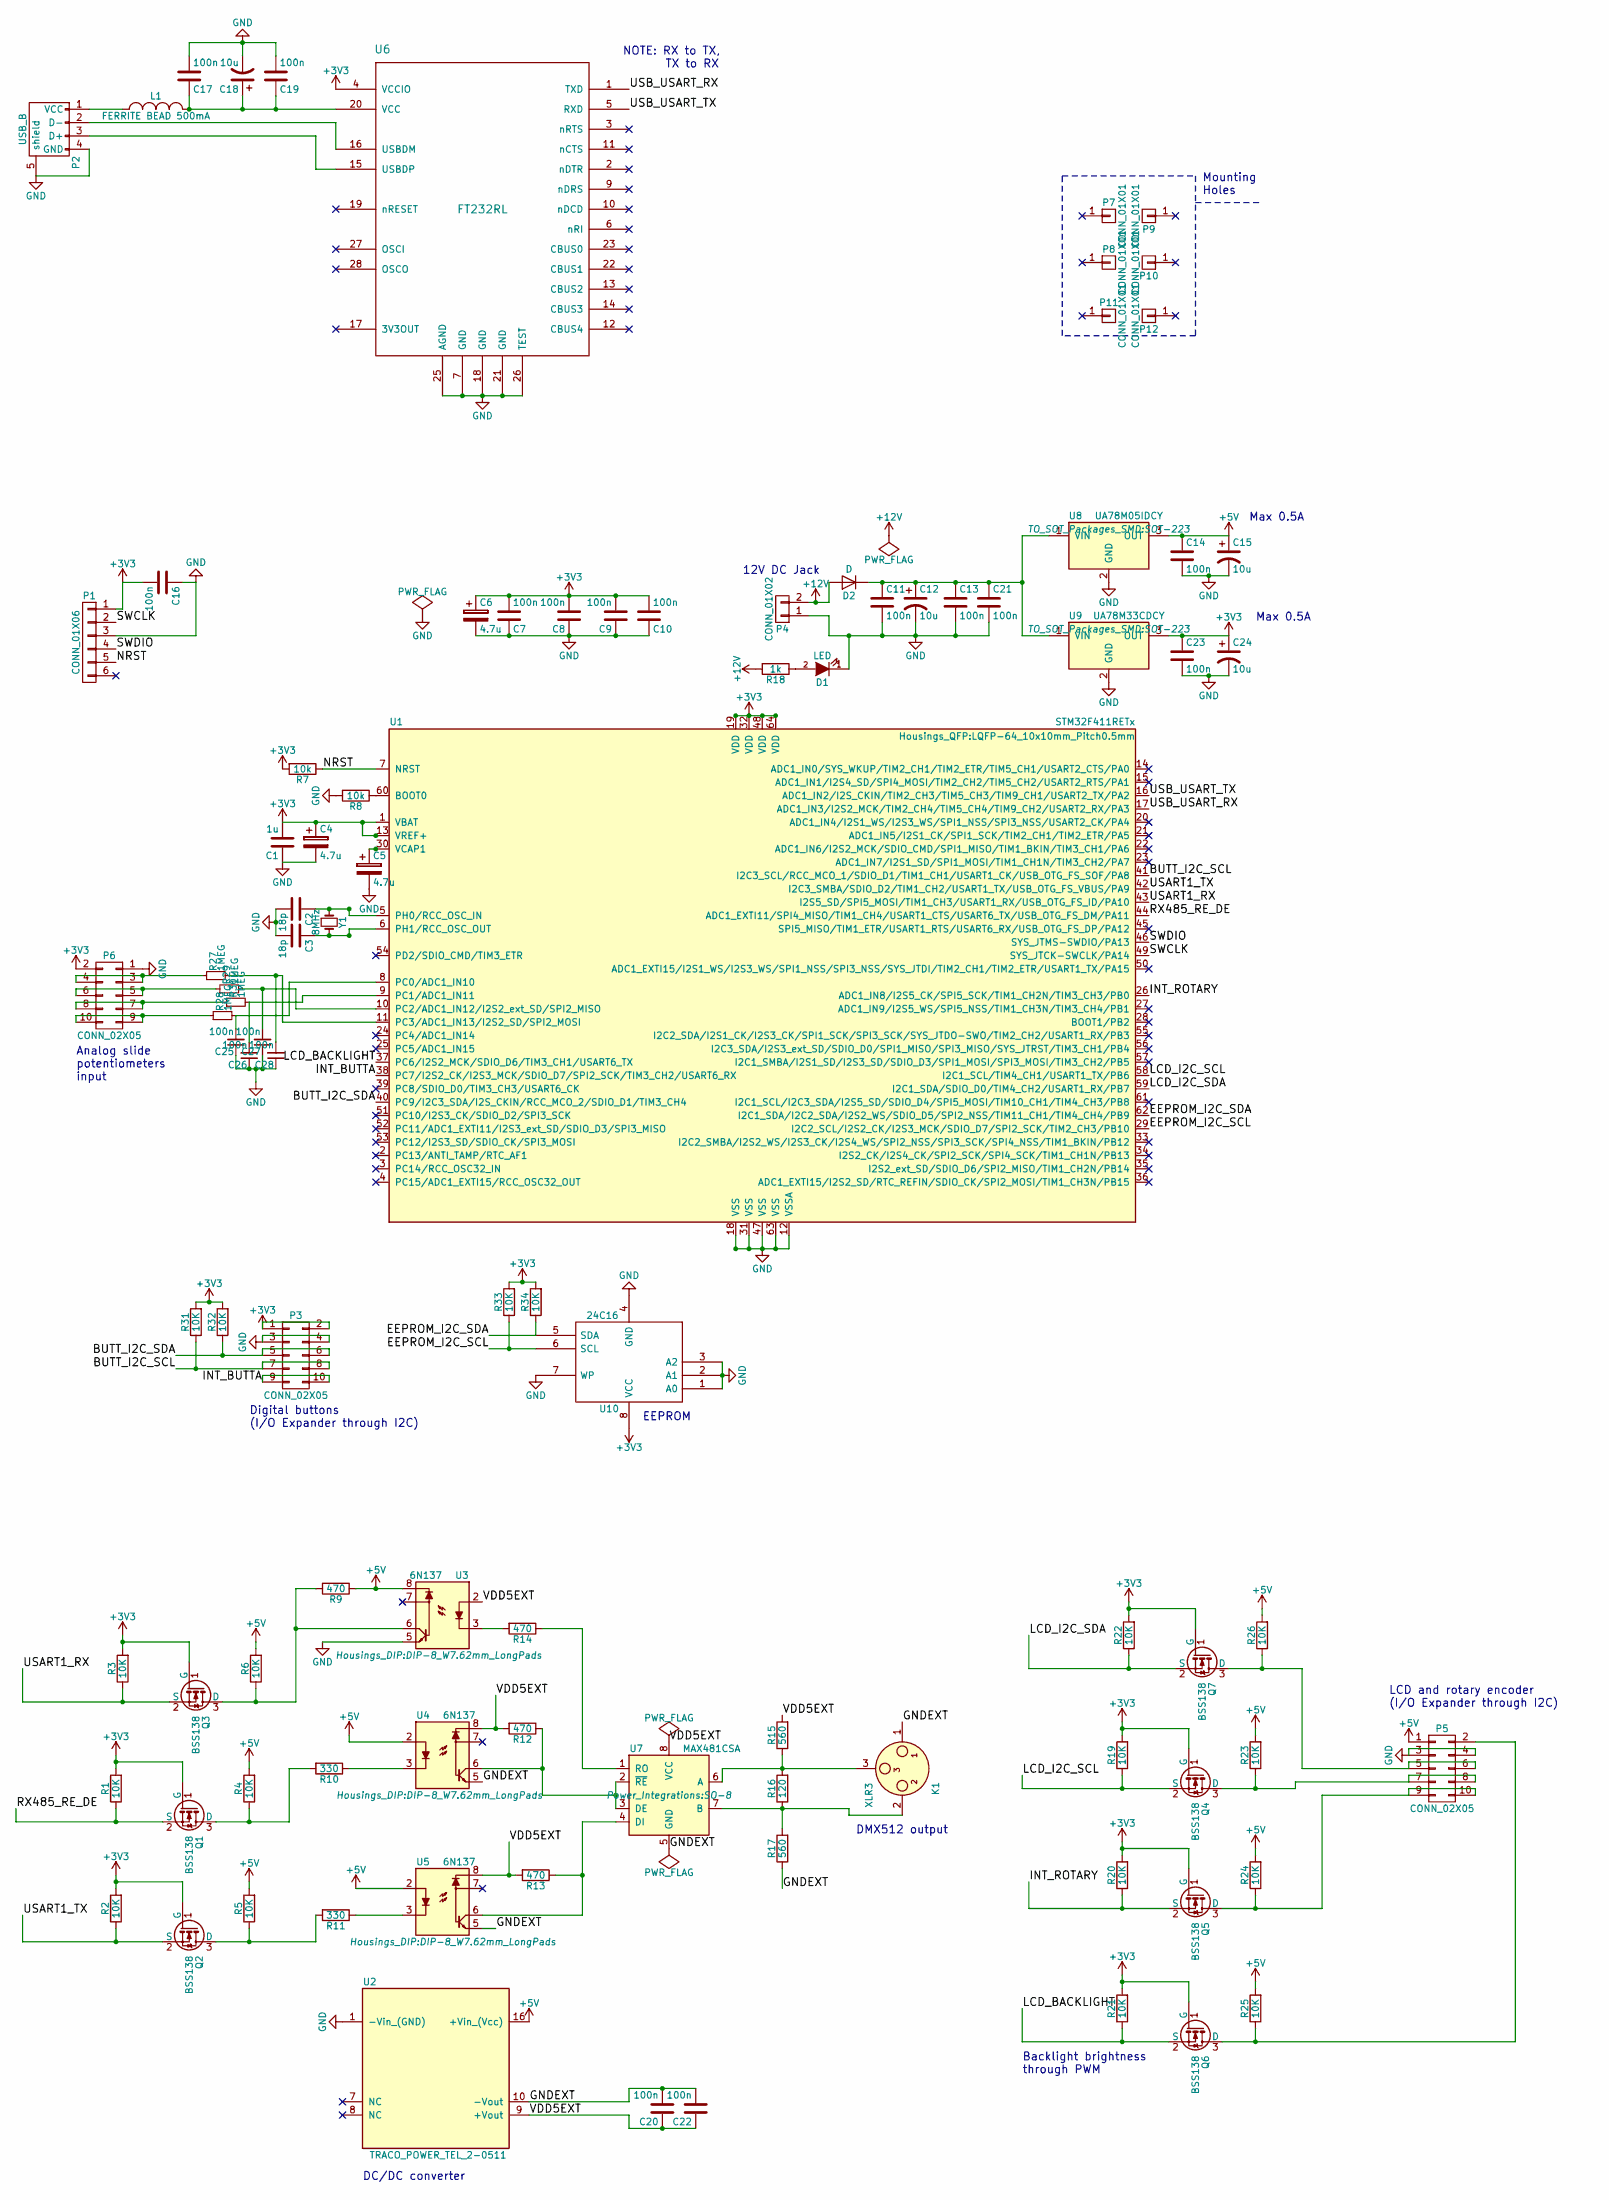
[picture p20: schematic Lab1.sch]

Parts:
C1: 1u; C_0603_HandSoldering
C2, C3: 18p; C_0603_HandSoldering
C4, C5, C6: 4.7u; CP_Tantalum_Case-A_EIA-3216-18_Reflow
C7, C8, C9, C10, C11, C13, C14, C16, C17, C19, C20, C21, C22, C23, C25, C26, C27, C28: 100n; C_0603_HandSoldering
C12, C15, C18, C24: 10u; CP_Tantalum_Case-A_EIA-3216-18_Reflow
D1: LED; LED_D5.0mm
D2: D; D_SOD-123
K1: XLR3; Pin_Header_Straight_1x03_Pitch1.27mm
L1: FERRITE BEAD 500mA; R_1206_HandSoldering
P1: CONN_01X06; Pin_Header_Straight_1x06_Pitch2.54mm
P2: USB_B
P3, P5, P6: CONN_02X05; Multicomp_MC9A22-1034_2x05x2.54mm_Angled
P4: CONN_01X02; Pin_Header_Straight_2x01_Pitch2.54mm
P7, P8, P9, P10, P11, P12: CONN_01X01; MountingHole_2.2mm_M2_DIN965_Pad
Q1, Q2, Q3, Q4, Q5, Q6, Q7: BSS138; SOT-23
R1, R2, R3, R4, R5, R6, R19, R20, R21, R22, R23, R24, R25, R26, R31, R32, R33, R34: 10K; R_0603_HandSoldering
R7, R8: 10k; R_0603_HandSoldering
R9, R12, R13, R14: 470; R_0603_HandSoldering
R10, R11: 330; R_0603_HandSoldering
R15, R17: 560; R_0603_HandSoldering
R16: 120; R_0603_HandSoldering
R18: 1k; R_0603_HandSoldering
R27, R28, R29, R30: 1MEG; R_0603_HandSoldering
U1: STM32F411RETx; LQFP-64_10x10mm_Pitch0.5mm
U2: TRACO_POWER_TEL_2-0511; TRACO_POWER_TEX_2-0511
U3, U4, U5: 6N137; DIP-8_W7.62mm_LongPads
U6: FT232RL; SSOP-28_5.3x10.2mm_Pitch0.65mm
U7: MAX481CSA; SO-8
U8: UA78M05IDCY; SOT-223
U9: UA78M33CDCY; SOT-223
U10: 24C16; SOIC-8_3.9x4.9mm_Pitch1.27mm
Y1: 8MHz; Crystal_SMD_HC49-SD

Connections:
+3V3: C1.2, C4.1, C6.1, C7.2, C8.2, C9.2, C10.2, C16.2, C23.1, C24.1, P1.1, P3.1, P3.2, P6.2, Q1.1 (G), Q2.1 (G), Q3.1 (G), Q4.1 (G), Q5.1 (G), Q6.1 (G), Q7.1 (G), R1.2, R2.2, R3.2, R7.2, R19.2, R20.2, R21.2, R22.2, R31.2, R32.2, R33.2, R34.2, U1.1 (VBAT), U1.13 (VREF+), U1.19 (VDD), U1.32 (VDD), U1.48 (VDD), U1.64 (VDD), U6.4 (VCCIO), U9.3 (OUT), U10.8 (VCC)
+5V: C14.1, C15.1, P5.1, R4.2, R5.2, R6.2, R9.1, R23.2, R24.2, R25.2, R26.2, U2.16 (+Vin_(Vcc)), U3.8, U4.2, U5.2, U8.3 (OUT)
+12V: D2.2 (A), P4.2, R18.2
/BUTT_I2C_SCL: P3.7, P3.8, R31.1, U1.41 (I2C3_SCL/RCC_MCO_1/SDIO_D1/TIM1_CH1/USA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)
/BUTT_I2C_SDA: P3.5, P3.6, R32.1, U1.40 (PC9/I2C3_SDA/I2S_CKIN/RCC_MCO_2/SDIO_D1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)
/EEPROM_I2C_SCL: R33.1, U1.29 (I2C2_SCL/I2S2_CK/I2S3_MCK/SDIO_D7/SPI2_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), U10.6 (SCL)
/EEPROM_I2C_SDA: R34.1, U1.62 (I2C1_SDA/I2C2_SDA/I2S2_WS/SDIO_D5/SPI2_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), U10.5 (SDA)
/GNDEXT: C20.2, C22.2, K1.1, R17.1, U2.10 (-Vout), U4.5, U5.5, U7.5 (GND)
/INT_BUTTA: P3.9, P3.10, U1.38 (PC7/I2S2_CK/I2S3_MCK/SDIO_D7/SPI2_SCK/T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)
/INT_ROTARY: Q5.2 (S), R20.1, U1.26 (ADC1_IN8/I2S5_CK/SPI5_SCK/TIM1_CH2N/TIM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)
/LCD_BACKLIGHT: Q6.2 (S), R21.1, U1.37 (PC6/I2S2_MCK/SDIO_D6/TIM3_CH1/USART6_TX)
/LCD_I2C_SCL: Q4.2 (S), R19.1, U1.58 (I2C1_SCL/TIM4_CH1/USART1_TX/PB6)
/LCD_I2C_SDA: Q7.2 (S), R22.1, U1.59 (I2C1_SDA/SDIO_D0/TIM4_CH2/USART1_RX/PB7)
/NRST: P1.5, R7.1, U1.7 (NRST)
/RX485_RE_DE: Q1.2 (S), R1.1, U1.44 (ADC1_EXTI11/SPI4_MISO/TIM1_CH4/USART1_C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)
/SWCLK: P1.2, U1.49 (SYS_JTCK-SWCLK/PA14)
/SWDIO: P1.4, U1.46 (SYS_JTMS-SWDIO/PA13)
/USART1_RX: Q3.2 (S), R3.1, U1.43 (I2S5_SD/SPI5_MOSI/TIM1_CH3/USART1_RX/US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)
/USART1_TX: Q2.2 (S), R2.1, U1.42 (I2C3_SMBA/SDIO_D2/TIM1_CH2/USART1_TX/US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)
/USB_USART_RX: U1.17 (ADC1_IN3/I2S2_MCK/TIM2_CH4/TIM5_CH4/TIM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), U6.1 (TXD)
/USB_USART_TX: U1.16 (ADC1_IN2/I2S_CKIN/TIM2_CH3/TIM5_CH3/TIM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), U6.5 (RXD)
/VDD5EXT: C20.1, C22.1, R12.2, R13.2, R15.2, U2.9 (+Vout), U3.2, U4.8, U5.8, U7.8 (VCC)
GND: C1.1, C2.2, C3.2, C4.2, C5.2, C6.2, C7.1, C8.1, C9.1, C10.1, C11.2, C12.2, C13.2, C14.2, C15.2, C16.1, C17.2, C18.2, C19.2, C21.2, C23.2, C24.2, C25.1, C26.1, C27.1, C28.1, D1.1 (K), P1.3, P2.4 (GND), P2.5 (shield), P3.3, P3.4, P4.1, P5.3, P5.4, P6.1, R8.2, U1.12 (VSSA), U1.18 (VSS), U1.31 (VSS), U1.47 (VSS), U1.63 (VSS), U2.1 (-Vin_(GND)), U3.5, U6.7 (GND), U6.18 (GND), U6.21 (GND), U6.25 (AGND), U6.26 (TEST), U8.2 (GND), U9.2 (GND), U10.1 (A0), U10.2 (A1), U10.3 (A2), U10.4 (GND), U10.7 (WP)
unnamed: C2.1, U1.5 (PH0/RCC_OSC_IN), Y1.1
unnamed: C3.1, U1.6 (PH1/RCC_OSC_OUT), Y1.2
unnamed: C5.1, U1.30 (VCAP1)
unnamed: C11.1, C12.1, C13.1, C21.1, D2.1 (K), U8.1 (VIN), U9.1 (VIN)
unnamed: C17.1, C18.1, C19.1, L1.2, U6.20 (VCC)
unnamed: C25.2, R28.2, U1.8 (PC0/ADC1_IN10)
unnamed: C26.2, R30.2, U1.9 (PC1/ADC1_IN11)
unnamed: C27.2, R29.2, U1.10 (PC2/ADC1_IN12/I2S2_ext_SD/SPI2_MISO)
unnamed: C28.2, R27.2, U1.11 (PC3/ADC1_IN13/I2S2_SD/SPI2_MOSI)
unnamed: D1.2 (A), R18.1
unnamed: K1.2, R16.1, R17.2, U7.7 (B)
unnamed: K1.3, R15.1, R16.2, U7.6 (A)
unnamed: L1.1, P2.1 (VCC)
unnamed: P2.2 (D-), U6.16 (USBDM)
unnamed: P2.3 (D+), U6.15 (USBDP)
unnamed: P5.2, Q6.3 (D), R25.1
unnamed: P5.5, P5.6, Q7.3 (D), R26.1
unnamed: P5.7, P5.8, Q4.3 (D), R23.1
unnamed: P5.9, P5.10, Q5.3 (D), R24.1
unnamed: P6.3, P6.4, R27.1
unnamed: P6.5, P6.6, R29.1
unnamed: P6.7, P6.8, R30.1
unnamed: P6.9, P6.10, R28.1
unnamed: Q1.3 (D), R4.1, R10.2
unnamed: Q2.3 (D), R5.1, R11.2
unnamed: Q3.3 (D), R6.1, R9.2, U3.6
unnamed: R8.1, U1.60 (BOOT0)
unnamed: R10.1, U4.3
unnamed: R11.1, U5.3
unnamed: R12.1, U4.6, U7.2 (~RE~), U7.3 (DE)
unnamed: R13.1, U5.6, U7.4 (DI)
unnamed: R14.1, U7.1 (RO)
unnamed: R14.2, U3.3

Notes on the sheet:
NOTE: RX to TX, TX to RX
Analog slide potentiometers input
EEPROM
LCD and rotary encoder (I/O Expander through I2C)
DMX512 output
Digital buttons (I/O Expander through I2C)
12V DC Jack
Max 0.5A
Backlight brightness through PWM
DC/DC converter
Mounting Holes

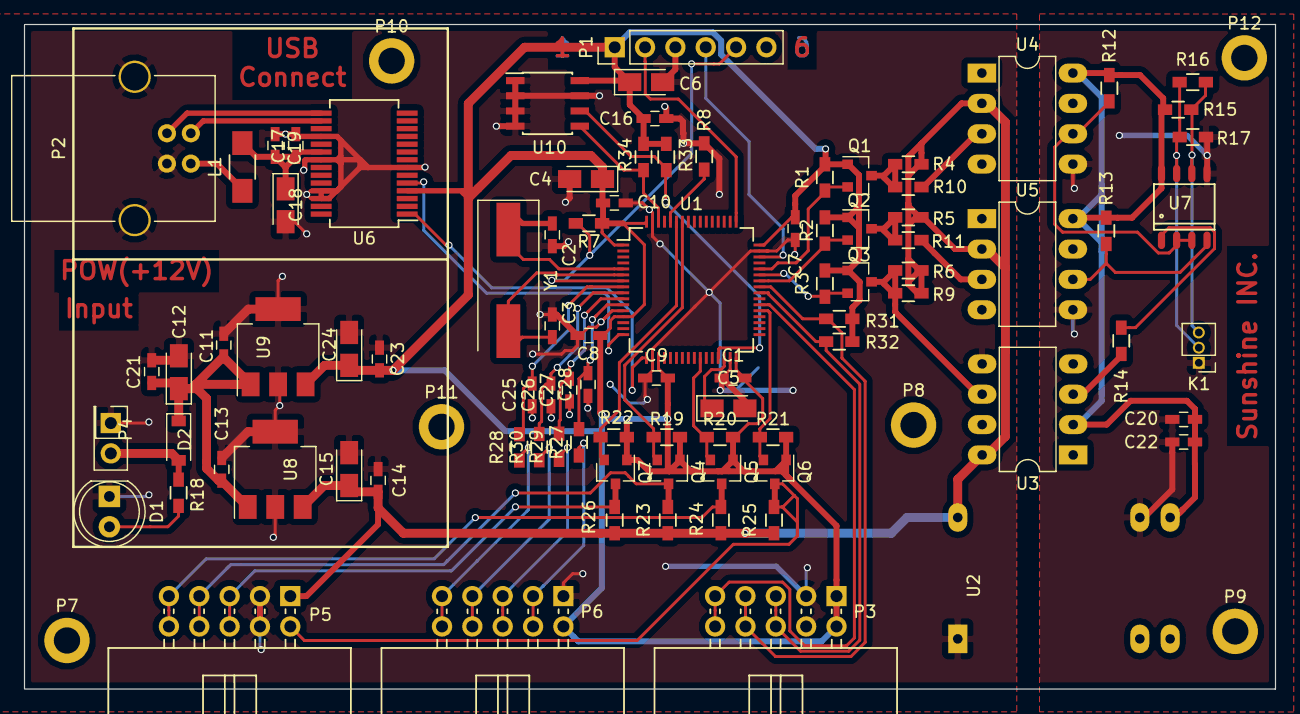
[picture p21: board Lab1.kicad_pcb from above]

Board: 2 copper layers, 104.7 x 55.6 mm, 96 parts (0 on the bottom side), 56 nets.

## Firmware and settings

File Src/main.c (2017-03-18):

/**
 ******************************************************************************
 * File Name          : main.c
 * Description        : Main program body
 ******************************************************************************
 *
 * COPYRIGHT(c) 2017 STMicroelectronics
 *
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
 ******************************************************************************
 */
/* Includes ------------------------------------------------------------------*/
#include "main.h"
#include "stm32f4xx_hal.h"

/* USER CODE BEGIN Includes */
#include <stdio.h>
#include <stdlib.h>
#include <stdint.h>

#include "serial.h"
#include "dmx512.h"
#include "eeprom.h"
#include "lcd.h"
#include "buttons.h"
#include "controller.h"
#include "sys_public.h"

/* USER CODE END Includes */

ADC_HandleTypeDef hadc1;
DMA_HandleTypeDef hdma_adc1;

I2C_HandleTypeDef hi2c1;
I2C_HandleTypeDef hi2c2;
I2C_HandleTypeDef hi2c3;
DMA_HandleTypeDef hdma_i2c1_tx;
DMA_HandleTypeDef hdma_i2c1_rx;
DMA_HandleTypeDef hdma_i2c2_rx;
DMA_HandleTypeDef hdma_i2c2_tx;
DMA_HandleTypeDef hdma_i2c3_rx;
DMA_HandleTypeDef hdma_i2c3_tx;

TIM_HandleTypeDef htim2;
TIM_HandleTypeDef htim3;
TIM_HandleTypeDef htim4;

UART_HandleTypeDef huart1;
UART_HandleTypeDef huart2;
DMA_HandleTypeDef hdma_usart1_tx;
DMA_HandleTypeDef hdma_usart2_rx;
DMA_HandleTypeDef hdma_usart2_tx;

/* USER CODE BEGIN PV */
volatile uint8_t adcFinished = 1;

/* USER CODE END PV */

void SystemClock_Config(void);
void Error_Handler(void);
static void MX_GPIO_Init(void);
static void MX_DMA_Init(void);
static void MX_ADC1_Init(void);
static void MX_I2C1_Init(void);
static void MX_I2C2_Init(void);
static void MX_I2C3_Init(void);
static void MX_TIM2_Init(void);
static void MX_TIM3_Init(void);
static void MX_USART1_UART_Init(void);
static void MX_USART2_UART_Init(void);
static void MX_TIM4_Init(void);

void HAL_TIM_MspPostInit(TIM_HandleTypeDef *htim);

/* USER CODE BEGIN PFP */

/* USER CODE END PFP */

/* USER CODE BEGIN 0 */
void EXTI15_10_IRQHandler(void) {
	// Blue button interrupt
	EXTI->PR |= B1_Pin;
}

void HAL_ADCEx_InjectedConvCpltCallback(ADC_HandleTypeDef* hadc) {
	// ADC has finished reading and converting the values on the four pins
	adcValues[0] = HAL_ADCEx_InjectedGetValue(&hadc1, ADC_INJECTED_RANK_1);
	adcValues[1] = HAL_ADCEx_InjectedGetValue(&hadc1, ADC_INJECTED_RANK_2);
	adcValues[2] = HAL_ADCEx_InjectedGetValue(&hadc1, ADC_INJECTED_RANK_3);
	adcValues[3] = HAL_ADCEx_InjectedGetValue(&hadc1, ADC_INJECTED_RANK_4);
	adcFinished = 1;
}

static uint16_t Buffercmp(uint8_t *pBuffer1, uint8_t *pBuffer2, uint16_t BufferLength) {
	while (BufferLength--) {
		uint8_t a = *pBuffer1;
		uint8_t b = *pBuffer2;
		if (a != b) {
			return 0;
		}
		pBuffer1++;
		pBuffer2++;
	}
	return 1;
}

int testEEPROM() {
	uint16_t len = 512;
	uint8_t data[len];
	uint8_t result[len];
	int i;
	for (i = 0; i < len; i++) {
		data[i] = 0;
	}
	for (i = 0; i < 9; i++) {
		EEPROMwrite(512 * i, (uint8_t *) data, len);
		while (!EEPROMfinished())
			;
		EEPROMread(512 * i, (uint8_t *) result, len);
		while (!EEPROMfinished())
			;
		if (!Buffercmp((uint8_t *) data, (uint8_t *) result, len))
			return 0;
	}
	return 1;
}
/* USER CODE END 0 */

int main(void) {

	/* MCU Configuration----------------------------------------------------------*/

	/* Reset of all peripherals, Initializes the Flash interface and the Systick. */
	HAL_Init();

	/* Configure the system clock */
	SystemClock_Config();

	/* Initialize all configured peripherals */
	MX_GPIO_Init();
	MX_DMA_Init();
	MX_ADC1_Init();
	MX_I2C1_Init();
	MX_I2C2_Init();
	MX_I2C3_Init();
	MX_TIM2_Init();
	MX_TIM3_Init();
	MX_USART1_UART_Init();
	MX_USART2_UART_Init();
	MX_TIM4_Init();

	/* USER CODE BEGIN 2 */
	LCDinit(&htim4, &htim3, &hi2c1);
	LCDfadeBrightness(100, 3);

	LCDclearRow(0);
	LCDcursorPos(0, 0);
	LCDwrite("ERROR COM");
	SerialInit(&huart2);

	LCDclearRow(0);
	LCDcursorPos(0, 0);
	LCDwrite("ERROR DMX");
	Dmx512Init(&htim2, &huart1);

	LCDclearRow(0);
	LCDcursorPos(0, 0);
	LCDwrite("ERROR EEPROM");
	EEPROMInit(&hi2c2);
//	if (!testEEPROM()) {
//		LCDcursorPos(0, 0);
//		LCDwrite("EEPROM Test failed");
//		while (1)
//			;
//	}

	LCDclearRow(0);
	LCDcursorPos(0, 0);
	LCDwrite("ERROR ADC");
	HAL_ADC_Start(&hadc1);

	LCDclearRow(0);
	LCDcursorPos(0, 0);
	LCDwrite("ERROR BUTTONS");
	ButtonsInit(&hi2c3);

	// Buttons I/O expander interrupt
	HAL_NVIC_EnableIRQ(EXTI9_5_IRQn);
	HAL_NVIC_SetPriority(EXTI9_5_IRQn, 0, 0);

	HAL_NVIC_EnableIRQ(EXTI0_IRQn);
	HAL_NVIC_SetPriority(EXTI0_IRQn, 0, 0);

	selectedDmxChannels[0] = 0;
	selectedDmxChannels[1] = 1;
	selectedDmxChannels[2] = 2;
	selectedDmxChannels[3] = 3;

	controllerMenuFunction = &ControllerEditProgram;
	prevControllerMenuFunction = &ControllerEditProgram;
	/* USER CODE END 2 */

	/* Infinite loop */
	/* USER CODE BEGIN WHILE */
	int i;
	while (1) {
		/* USER CODE END WHILE */

		/* USER CODE BEGIN 3 */
		if (adcFinished) {
			adcFinished = 0;
			HAL_ADCEx_InjectedStart_IT(&hadc1);
			for (i = 0; i < 4; i++) {
				if (!selectedDmxInputLock[i])
					Dmx512SetChannelValue(selectedDmxChannels[i], adcValues[i]);
			}
		}
		ControllerUpdate();
	}
	/* USER CODE END 3 */
}

/** System Clock Configuration
 */
void SystemClock_Config(void) {

	RCC_OscInitTypeDef RCC_OscInitStruct;
	RCC_ClkInitTypeDef RCC_ClkInitStruct;

	/**Configure the main internal regulator output voltage
	 */
	__HAL_RCC_PWR_CLK_ENABLE()
	;

	__HAL_PWR_VOLTAGESCALING_CONFIG(PWR_REGULATOR_VOLTAGE_SCALE1);

	/**Initializes the CPU, AHB and APB busses clocks
	 */
	RCC_OscInitStruct.OscillatorType = RCC_OSCILLATORTYPE_HSE;
	RCC_OscInitStruct.HSEState = RCC_HSE_ON;
	RCC_OscInitStruct.PLL.PLLState = RCC_PLL_ON;
	RCC_OscInitStruct.PLL.PLLSource = RCC_PLLSOURCE_HSE;
	RCC_OscInitStruct.PLL.PLLM = 4;
	RCC_OscInitStruct.PLL.PLLN = 160;
	RCC_OscInitStruct.PLL.PLLP = RCC_PLLP_DIV4;
	RCC_OscInitStruct.PLL.PLLQ = 4;
	if (HAL_RCC_OscConfig(&RCC_OscInitStruct) != HAL_OK) {
		Error_Handler();
	}

	/**Initializes the CPU, AHB and APB busses clocks
	 */
	RCC_ClkInitStruct.ClockType = RCC_CLOCKTYPE_HCLK | RCC_CLOCKTYPE_SYSCLK | RCC_CLOCKTYPE_PCLK1 | RCC_CLOCKTYPE_PCLK2;
	RCC_ClkInitStruct.SYSCLKSource = RCC_SYSCLKSOURCE_PLLCLK;
	RCC_ClkInitStruct.AHBCLKDivider = RCC_SYSCLK_DIV1;
	RCC_ClkInitStruct.APB1CLKDivider = RCC_HCLK_DIV2;
	RCC_ClkInitStruct.APB2CLKDivider = RCC_HCLK_DIV1;

	if (HAL_RCC_ClockConfig(&RCC_ClkInitStruct, FLASH_LATENCY_2) != HAL_OK) {
		Error_Handler();
	}

	/**Configure the Systick interrupt time
	 */
	HAL_SYSTICK_Config(HAL_RCC_GetHCLKFreq() / 1000);

	/**Configure the Systick
	 */
	HAL_SYSTICK_CLKSourceConfig(SYSTICK_CLKSOURCE_HCLK);

	/* SysTick_IRQn interrupt configuration */
	HAL_NVIC_SetPriority(SysTick_IRQn, 0, 0);
}

/* ADC1 init function */
static void MX_ADC1_Init(void) {

//	ADC_ChannelConfTypeDef sConfig;
	ADC_InjectionConfTypeDef sConfigInjected;

	/**Configure the global features of the ADC (Clock, Resolution, Data Alignment and number of conversion)
	 */
	hadc1.Instance = ADC1;
	hadc1.Init.ClockPrescaler = ADC_CLOCK_SYNC_PCLK_DIV4;
	hadc1.Init.Resolution = ADC_RESOLUTION_8B;
	hadc1.Init.ScanConvMode = ENABLE;
	hadc1.Init.ContinuousConvMode = DISABLE;
	hadc1.Init.DiscontinuousConvMode = DISABLE;
	hadc1.Init.ExternalTrigConvEdge = ADC_EXTERNALTRIGCONVEDGE_NONE;
	hadc1.Init.ExternalTrigConv = ADC_SOFTWARE_START;
	hadc1.Init.DataAlign = ADC_DATAALIGN_RIGHT;
	hadc1.Init.NbrOfConversion = 4;
	hadc1.Init.DMAContinuousRequests = ENABLE;
	hadc1.Init.EOCSelection = ADC_EOC_SEQ_CONV;
	if (HAL_ADC_Init(&hadc1) != HAL_OK) {
		Error_Handler();
	}

//	/**Configure for the selected ADC regular channel its corresponding rank in the sequencer and its sample time.
//	 */
//	sConfig.Channel = ADC_CHANNEL_10;
//	sConfig.Rank = 1;
//	sConfig.SamplingTime = ADC_SAMPLETIME_84CYCLES;
//	if (HAL_ADC_ConfigChannel(&hadc1, &sConfig) != HAL_OK) {
//		Error_Handler();
//	}
//
//	/**Configure for the selected ADC regular channel its corresponding rank in the sequencer and its sample time.
//	 */
//	sConfig.Channel = ADC_CHANNEL_11;
//	sConfig.Rank = 2;
//	if (HAL_ADC_ConfigChannel(&hadc1, &sConfig) != HAL_OK) {
//		Error_Handler();
//	}
//
//	/**Configure for the selected ADC regular channel its corresponding rank in the sequencer and its sample time.
//	 */
//	sConfig.Channel = ADC_CHANNEL_12;
//	sConfig.Rank = 3;
//	if (HAL_ADC_ConfigChannel(&hadc1, &sConfig) != HAL_OK) {
//		Error_Handler();
//	}
//
//	/**Configure for the selected ADC regular channel its corresponding rank in the sequencer and its sample time.
//	 */
//	sConfig.Channel = ADC_CHANNEL_13;
//	sConfig.Rank = 4;
//	if (HAL_ADC_ConfigChannel(&hadc1, &sConfig) != HAL_OK) {
//		Error_Handler();
//	}

	/**Configures for the selected ADC injected channel its corresponding rank in the sequencer and its sample time
	 */
	sConfigInjected.InjectedChannel = ADC_CHANNEL_10;
	sConfigInjected.InjectedRank = 1;
	sConfigInjected.InjectedNbrOfConversion = 4;
	sConfigInjected.InjectedSamplingTime = ADC_SAMPLETIME_3CYCLES;
	sConfigInjected.ExternalTrigInjecConvEdge = ADC_EXTERNALTRIGINJECCONVEDGE_NONE;
	sConfigInjected.ExternalTrigInjecConv = ADC_INJECTED_SOFTWARE_START;
	sConfigInjected.AutoInjectedConv = DISABLE;
	sConfigInjected.InjectedDiscontinuousConvMode = DISABLE;
	sConfigInjected.InjectedOffset = 0;
	if (HAL_ADCEx_InjectedConfigChannel(&hadc1, &sConfigInjected) != HAL_OK) {
		Error_Handler();
	}

	/**Configures for the selected ADC injected channel its corresponding rank in the sequencer and its sample time
	 */
	sConfigInjected.InjectedChannel = ADC_CHANNEL_11;
	sConfigInjected.InjectedRank = 2;
	if (HAL_ADCEx_InjectedConfigChannel(&hadc1, &sConfigInjected) != HAL_OK) {
		Error_Handler();
	}

	/**Configures for the selected ADC injected channel its corresponding rank in the sequencer and its sample time
	 */
	sConfigInjected.InjectedChannel = ADC_CHANNEL_12;
	sConfigInjected.InjectedRank = 3;
	if (HAL_ADCEx_InjectedConfigChannel(&hadc1, &sConfigInjected) != HAL_OK) {
		Error_Handler();
	}

	/**Configures for the selected ADC injected channel its corresponding rank in the sequencer and its sample time
	 */
	sConfigInjected.InjectedChannel = ADC_CHANNEL_13;
	sConfigInjected.InjectedRank = 4;
	if (HAL_ADCEx_InjectedConfigChannel(&hadc1, &sConfigInjected) != HAL_OK) {
		Error_Handler();
	}

}

/* I2C1 init function */
static void MX_I2C1_Init(void) {

	hi2c1.Instance = I2C1;
	hi2c1.Init.ClockSpeed = 400000;
	hi2c1.Init.DutyCycle = I2C_DUTYCYCLE_2;
	hi2c1.Init.OwnAddress1 = 0;
	hi2c1.Init.AddressingMode = I2C_ADDRESSINGMODE_7BIT;
	hi2c1.Init.DualAddressMode = I2C_DUALADDRESS_DISABLE;
	hi2c1.Init.OwnAddress2 = 0;
	hi2c1.Init.GeneralCallMode = I2C_GENERALCALL_DISABLE;
	hi2c1.Init.NoStretchMode = I2C_NOSTRETCH_DISABLE;
	if (HAL_I2C_Init(&hi2c1) != HAL_OK) {
		Error_Handler();
	}

}

/* I2C2 init function */
static void MX_I2C2_Init(void) {

	hi2c2.Instance = I2C2;
	hi2c2.Init.ClockSpeed = 400000;
	hi2c2.Init.DutyCycle = I2C_DUTYCYCLE_2;
	hi2c2.Init.OwnAddress1 = 0;
	hi2c2.Init.AddressingMode = I2C_ADDRESSINGMODE_7BIT;
	hi2c2.Init.DualAddressMode = I2C_DUALADDRESS_DISABLE;
	hi2c2.Init.OwnAddress2 = 0;
	hi2c2.Init.GeneralCallMode = I2C_GENERALCALL_DISABLE;
	hi2c2.Init.NoStretchMode = I2C_NOSTRETCH_DISABLE;
	if (HAL_I2C_Init(&hi2c2) != HAL_OK) {
		Error_Handler();
	}

}

/* I2C3 init function */
static void MX_I2C3_Init(void) {

	hi2c3.Instance = I2C3;
	hi2c3.Init.ClockSpeed = 400000;
	hi2c3.Init.DutyCycle = I2C_DUTYCYCLE_2;
	hi2c3.Init.OwnAddress1 = 0;
	hi2c3.Init.AddressingMode = I2C_ADDRESSINGMODE_7BIT;
	hi2c3.Init.DualAddressMode = I2C_DUALADDRESS_DISABLE;
	hi2c3.Init.OwnAddress2 = 0;
	hi2c3.Init.GeneralCallMode = I2C_GENERALCALL_DISABLE;
	hi2c3.Init.NoStretchMode = I2C_NOSTRETCH_DISABLE;
	if (HAL_I2C_Init(&hi2c3) != HAL_OK) {
		Error_Handler();
	}

}

/* TIM2 init function */
static void MX_TIM2_Init(void) {

	TIM_ClockConfigTypeDef sClockSourceConfig;
	TIM_MasterConfigTypeDef sMasterConfig;

	htim2.Instance = TIM2;
	htim2.Init.Prescaler = 79;
	htim2.Init.CounterMode = TIM_COUNTERMODE_UP;
	htim2.Init.Period = 0xFFFFFFFF;
	htim2.Init.ClockDivision = TIM_CLOCKDIVISION_DIV1;
	if (HAL_TIM_Base_Init(&htim2) != HAL_OK) {
		Error_Handler();
	}

	sClockSourceConfig.ClockSource = TIM_CLOCKSOURCE_INTERNAL;
	if (HAL_TIM_ConfigClockSource(&htim2, &sClockSourceConfig) != HAL_OK) {
		Error_Handler();
	}

	sMasterConfig.MasterOutputTrigger = TIM_TRGO_RESET;
	sMasterConfig.MasterSlaveMode = TIM_MASTERSLAVEMODE_DISABLE;
	if (HAL_TIMEx_MasterConfigSynchronization(&htim2, &sMasterConfig) != HAL_OK) {
		Error_Handler();
	}

}

/* TIM3 init function */
static void MX_TIM3_Init(void) {

	TIM_ClockConfigTypeDef sClockSourceConfig;
	TIM_MasterConfigTypeDef sMasterConfig;
	TIM_OC_InitTypeDef sConfigOC;

	htim3.Instance = TIM3;
	htim3.Init.Prescaler = 0;
	htim3.Init.CounterMode = TIM_COUNTERMODE_UP;
	htim3.Init.Period = 100;
	htim3.Init.ClockDivision = TIM_CLOCKDIVISION_DIV1;
	if (HAL_TIM_Base_Init(&htim3) != HAL_OK) {
		Error_Handler();
	}

	sClockSourceConfig.ClockSource = TIM_CLOCKSOURCE_INTERNAL;
	if (HAL_TIM_ConfigClockSource(&htim3, &sClockSourceConfig) != HAL_OK) {
		Error_Handler();
	}

	if (HAL_TIM_PWM_Init(&htim3) != HAL_OK) {
		Error_Handler();
	}

	sMasterConfig.MasterOutputTrigger = TIM_TRGO_RESET;
	sMasterConfig.MasterSlaveMode = TIM_MASTERSLAVEMODE_DISABLE;
	if (HAL_TIMEx_MasterConfigSynchronization(&htim3, &sMasterConfig) != HAL_OK) {
		Error_Handler();
	}

	sConfigOC.OCMode = TIM_OCMODE_PWM1;
	sConfigOC.Pulse = 0;
	sConfigOC.OCPolarity = TIM_OCPOLARITY_HIGH;
	sConfigOC.OCFastMode = TIM_OCFAST_DISABLE;
	if (HAL_TIM_PWM_ConfigChannel(&htim3, &sConfigOC, TIM_CHANNEL_1) != HAL_OK) {
		Error_Handler();
	}

	HAL_TIM_MspPostInit(&htim3);

}

/* TIM4 init function */
static void MX_TIM4_Init(void) {

	TIM_ClockConfigTypeDef sClockSourceConfig;
	TIM_MasterConfigTypeDef sMasterConfig;

	htim4.Instance = TIM4;
	htim4.Init.Prescaler = 79;
	htim4.Init.CounterMode = TIM_COUNTERMODE_UP;
	htim4.Init.Period = 0xFFFF;
	htim4.Init.ClockDivision = TIM_CLOCKDIVISION_DIV1;
	if (HAL_TIM_Base_Init(&htim4) != HAL_OK) {
		Error_Handler();
	}

	sClockSourceConfig.ClockSource = TIM_CLOCKSOURCE_INTERNAL;
	if (HAL_TIM_ConfigClockSource(&htim4, &sClockSourceConfig) != HAL_OK) {
		Error_Handler();
	}

	sMasterConfig.MasterOutputTrigger = TIM_TRGO_RESET;
	sMasterConfig.MasterSlaveMode = TIM_MASTERSLAVEMODE_DISABLE;
	if (HAL_TIMEx_MasterConfigSynchronization(&htim4, &sMasterConfig) != HAL_OK) {
		Error_Handler();
	}

}

/* USART1 init function */
static void MX_USART1_UART_Init(void) {

	huart1.Instance = USART1;
	huart1.Init.BaudRate = 250000;
	huart1.Init.WordLength = UART_WORDLENGTH_8B;
	huart1.Init.StopBits = UART_STOPBITS_2;
	huart1.Init.Parity = UART_PARITY_NONE;
	huart1.Init.Mode = UART_MODE_TX;
	huart1.Init.HwFlowCtl = UART_HWCONTROL_NONE;
	huart1.Init.OverSampling = UART_OVERSAMPLING_16;
	if (HAL_UART_Init(&huart1) != HAL_OK) {
		Error_Handler();
	}

}

/* USART2 init function */
static void MX_USART2_UART_Init(void) {

	huart2.Instance = USART2;
	huart2.Init.BaudRate = 250000;
	huart2.Init.WordLength = UART_WORDLENGTH_8B;
	huart2.Init.StopBits = UART_STOPBITS_2;
	huart2.Init.Parity = UART_PARITY_NONE;
	huart2.Init.Mode = UART_MODE_TX_RX;
	huart2.Init.HwFlowCtl = UART_HWCONTROL_NONE;
	huart2.Init.OverSampling = UART_OVERSAMPLING_16;
	if (HAL_UART_Init(&huart2) != HAL_OK) {
		Error_Handler();
	}
}

/** 
 * Enable DMA controller clock
 */
static void MX_DMA_Init(void) {
	/* DMA controller clock enable */
	__HAL_RCC_DMA1_CLK_ENABLE()
	;
	__HAL_RCC_DMA2_CLK_ENABLE()
	;

	/* DMA interrupt init */
	/* DMA1_Stream0_IRQn interrupt configuration */
	HAL_NVIC_SetPriority(DMA1_Stream0_IRQn, 0, 0);
	HAL_NVIC_EnableIRQ(DMA1_Stream0_IRQn);
	/* DMA1_Stream1_IRQn interrupt configuration */
	HAL_NVIC_SetPriority(DMA1_Stream1_IRQn, 0, 0);
	HAL_NVIC_EnableIRQ(DMA1_Stream1_IRQn);
	/* DMA1_Stream2_IRQn interrupt configuration */
	HAL_NVIC_SetPriority(DMA1_Stream2_IRQn, 0, 0);
	HAL_NVIC_EnableIRQ(DMA1_Stream2_IRQn);
	/* DMA1_Stream3_IRQn interrupt configuration */
	HAL_NVIC_SetPriority(DMA1_Stream3_IRQn, 0, 0);
	HAL_NVIC_EnableIRQ(DMA1_Stream3_IRQn);
	/* DMA1_Stream4_IRQn interrupt configuration */
	HAL_NVIC_SetPriority(DMA1_Stream4_IRQn, 0, 0);
	HAL_NVIC_EnableIRQ(DMA1_Stream4_IRQn);
	/* DMA1_Stream5_IRQn interrupt configuration */
	HAL_NVIC_SetPriority(DMA1_Stream5_IRQn, 0, 0);
	HAL_NVIC_EnableIRQ(DMA1_Stream5_IRQn);
	/* DMA1_Stream6_IRQn interrupt configuration */
	HAL_NVIC_SetPriority(DMA1_Stream6_IRQn, 0, 0);
	HAL_NVIC_EnableIRQ(DMA1_Stream6_IRQn);
	/* DMA1_Stream7_IRQn interrupt configuration */
	HAL_NVIC_SetPriority(DMA1_Stream7_IRQn, 0, 0);
	HAL_NVIC_EnableIRQ(DMA1_Stream7_IRQn);
	/* DMA2_Stream0_IRQn interrupt configuration */
	HAL_NVIC_SetPriority(DMA2_Stream0_IRQn, 0, 0);
	HAL_NVIC_EnableIRQ(DMA2_Stream0_IRQn);
	/* DMA2_Stream7_IRQn interrupt configuration */
	HAL_NVIC_SetPriority(DMA2_Stream7_IRQn, 0, 0);
	HAL_NVIC_EnableIRQ(DMA2_Stream7_IRQn);

}

/** Configure pins as 
 * Analog
 * Input
 * Output
 * EVENT_OUT
 * EXTI
 */
static void MX_GPIO_Init(void) {

	GPIO_InitTypeDef GPIO_InitStruct;

	/* GPIO Ports Clock Enable */
	__HAL_RCC_GPIOC_CLK_ENABLE()
	;
	__HAL_RCC_GPIOH_CLK_ENABLE()
	;
	__HAL_RCC_GPIOA_CLK_ENABLE()
	;
	__HAL_RCC_GPIOB_CLK_ENABLE()
	;

	/*Configure GPIO pin Output Level */
	HAL_GPIO_WritePin(LD2_GPIO_Port, LD2_Pin, GPIO_PIN_RESET);

	/*Configure GPIO pin Output Level */
	HAL_GPIO_WritePin(DMX_EN_GPIO_Port, DMX_EN_Pin, GPIO_PIN_SET);

	/*Configure GPIO pin : B1_Pin */
	GPIO_InitStruct.Pin = B1_Pin;
	GPIO_InitStruct.Mode = GPIO_MODE_IT_FALLING;
	GPIO_InitStruct.Pull = GPIO_NOPULL;
	HAL_GPIO_Init(B1_GPIO_Port, &GPIO_InitStruct);

	/*Configure GPIO pins : LD2_Pin DMX_EN_Pin */
	GPIO_InitStruct.Pin = LD2_Pin | DMX_EN_Pin;
	GPIO_InitStruct.Mode = GPIO_MODE_OUTPUT_PP;
	GPIO_InitStruct.Pull = GPIO_NOPULL;
	GPIO_InitStruct.Speed = GPIO_SPEED_FREQ_LOW;
	HAL_GPIO_Init(GPIOA, &GPIO_InitStruct);

	/*Configure GPIO pin : B0_Pin */
	GPIO_InitStruct.Pin = B0_Pin;
	GPIO_InitStruct.Mode = GPIO_MODE_IT_RISING;
	GPIO_InitStruct.Pull = GPIO_NOPULL;
	HAL_GPIO_Init(B0_GPIO_Port, &GPIO_InitStruct);

	/*Configure GPIO pin : B2_Pin */
	GPIO_InitStruct.Pin = B2_Pin;
	GPIO_InitStruct.Mode = GPIO_MODE_IT_RISING;
	GPIO_InitStruct.Pull = GPIO_NOPULL;
	HAL_GPIO_Init(B2_GPIO_Port, &GPIO_InitStruct);

}

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


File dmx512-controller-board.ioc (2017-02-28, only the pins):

Mcu.UserName=STM32F411RETx
PA10.GPIO_Label=DMX_RX
PA10.Signal=USART1_RX
PA11.GPIO_Label=DMX_EN
PA11.Signal=GPIO_Output
PA13.GPIO_Label=TMS
PA13.Signal=SYS_JTMS-SWDIO
PA14.GPIO_Label=TCK
PA14.Signal=SYS_JTCK-SWCLK
PA2.GPIO_Label=USB_TX
PA2.Signal=USART2_TX
PA3.GPIO_Label=USB_RX
PA3.Signal=USART2_RX
PA5.GPIO_Label=LD2 [Green Led]
PA5.Signal=GPIO_Output
PA8.GPIO_Label=BUTTONS_SCL
PA8.Signal=I2C3_SCL
PA9.GPIO_Label=DMX_TX
PA9.Signal=USART1_TX
PB0.GPIO_Label=B0 [RotEnc INT0]
PB0.Signal=GPXTI0
PB10.GPIO_Label=EEPROM_SCL
PB10.Signal=I2C2_SCL
PB3.GPIO_Label=SWO
PB3.Signal=SYS_JTDO-SWO
PB6.GPIO_Label=LCD_SCL
PB6.Signal=I2C1_SCL
PB7.GPIO_Label=LCD_SDA
PB7.Signal=I2C1_SDA
PB9.GPIO_Label=EEPROM_SDA
PB9.Signal=I2C2_SDA
PC0.Signal=ADCx_IN10
PC1.Signal=ADCx_IN11
PC13-ANTI_TAMP.GPIO_Label=B1 [Blue PushButton]
PC13-ANTI_TAMP.Signal=GPXTI13
PC14-OSC32_IN.Signal=RCC_OSC32_IN
PC15-OSC32_OUT.Signal=RCC_OSC32_OUT
PC2.Signal=ADCx_IN12
PC3.Signal=ADCx_IN13
PC6.GPIO_Label=LCD_BL
PC6.Signal=S_TIM3_CH1
PC7.GPIO_Label=B2 [Button INT0]
PC7.Signal=GPXTI7
PC9.GPIO_Label=BUTTONS_SDA
PC9.Signal=I2C3_SDA

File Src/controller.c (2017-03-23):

#include "controller.h"

#define MAX_CMD_BUF	10

static enum buttonEnum uCmdBuffer[MAX_CMD_BUF];
static uint8_t uCmdState[MAX_CMD_BUF];
static int uCmdIndex = 0;
static int uCmdOutdex = 0;

static volatile uint8_t newDmxDataLoaded = 0;

static volatile int encPosition;

static volatile uint8_t selectedDmxProgram;
static volatile int8_t mainMenuCursor;
static volatile uint8_t mainMenuEditLCDbacklightMode;
static volatile uint8_t mainMenuProgramWasSaved;

int ControllerPopCmd(enum buttonEnum *button, int *buttonState) {
	// Pop a character from the FIFO
	if (uCmdIndex == uCmdOutdex)
		return 0;
	*button = uCmdBuffer[uCmdOutdex];
	*buttonState = uCmdState[uCmdOutdex];
	uCmdOutdex = (uCmdOutdex + 1) % MAX_CMD_BUF;
	return 1;
}

int ControllerQueueCmd(enum buttonEnum button, int buttonState) {
	// Put a cmd in the FIFO
	if (uCmdIndex == ((uCmdOutdex - 1 + MAX_CMD_BUF) % MAX_CMD_BUF))
		return 0;
	uCmdBuffer[uCmdIndex] = button;
	uCmdState[uCmdIndex] = buttonState;
	uCmdIndex = (uCmdIndex + 1) % MAX_CMD_BUF;
	return 1;
}

void ControlleSetSelectedDMXchannels(int steps) {
	selectedDmxChannels[0] = (((uint16_t) (selectedDmxChannels[0] + steps)) % 512);
	selectedDmxChannels[1] = (((uint16_t) (selectedDmxChannels[1] + steps)) % 512);
	selectedDmxChannels[2] = (((uint16_t) (selectedDmxChannels[2] + steps)) % 512);
	selectedDmxChannels[3] = (((uint16_t) (selectedDmxChannels[3] + steps)) % 512);
}

void ControllerLockDMXinput(void) {
	selectedDmxInputLock[0] = 1;
	ButtonSetLED(&buttonMap[BTN_S1], 1);
	selectedDmxInputLock[1] = 1;
	ButtonSetLED(&buttonMap[BTN_S2], 1);
	selectedDmxInputLock[2] = 1;
	ButtonSetLED(&buttonMap[BTN_S3], 1);
	selectedDmxInputLock[3] = 1;
	ButtonSetLED(&buttonMap[BTN_S4], 1);
}

void ControllerLoadDMXprogram(int program) {
	if (program == 0)
		return;
	ControllerLockDMXinput();
	EEPROMread(DMX_CHANNELS * program, tmpDmxData, DMX_CHANNELS);
	newDmxDataLoaded = 1;
}

void ControllerSaveDMXprogram(int program) {
	if (program == 0)
		return;
	memcpy(tmpDmxData, &dmxData[1], DMX_CHANNELS * sizeof(uint8_t));
	EEPROMwrite(DMX_CHANNELS * program, tmpDmxData, DMX_CHANNELS);
}

void ControllerEditProgram(enum buttonEnum button, int buttonState) {
	if (button == ENC_CW || button == ENC_CCW || button == BTN_ENC)
		ControllerLockDMXinput();

	if (buttonState == BUTTON_PRESSED) {

		switch (button) {
		case BTN_ENC:
			selectedDmxChannels[0] = 0;
			selectedDmxChannels[1] = 1;
			selectedDmxChannels[2] = 2;
			selectedDmxChannels[3] = 3;
			break;
		case ENC_CW:
			ControlleSetSelectedDMXchannels(4);
			break;
		case ENC_CCW:
			ControlleSetSelectedDMXchannels(-4);
			break;

		case BTN_F1:
			selectedDmxProgram = 1;
			ControllerLoadDMXprogram(selectedDmxProgram);
			ButtonSetFNbuttonLEDS(0);
			ButtonSetLED(&buttonMap[BTN_F1], 1);
			return;
		case BTN_F2:
			selectedDmxProgram = 2;
			ControllerLoadDMXprogram(selectedDmxProgram);
			ButtonSetFNbuttonLEDS(0);
			ButtonSetLED(&buttonMap[BTN_F2], 1);
			return;
		case BTN_F3:
			selectedDmxProgram = 3;
			ControllerLoadDMXprogram(selectedDmxProgram);
			ButtonSetFNbuttonLEDS(0);
			ButtonSetLED(&buttonMap[BTN_F3], 1);
			return;
		case BTN_F4:
			selectedDmxProgram = 4;
			ControllerLoadDMXprogram(selectedDmxProgram);
			ButtonSetFNbuttonLEDS(0);
			ButtonSetLED(&buttonMap[BTN_F4], 1);
			return;
		case BTN_F5:
			selectedDmxProgram = 5;
			ControllerLoadDMXprogram(selectedDmxProgram);
			ButtonSetFNbuttonLEDS(0);
			ButtonSetLED(&buttonMap[BTN_F5], 1);
			return;
		case BTN_F6:
			selectedDmxProgram = 6;
			ControllerLoadDMXprogram(selectedDmxProgram);
			ButtonSetFNbuttonLEDS(0);
			ButtonSetLED(&buttonMap[BTN_F6], 1);
			return;
		case BTN_F7:
			selectedDmxProgram = 7;
			ControllerLoadDMXprogram(selectedDmxProgram);
			ButtonSetFNbuttonLEDS(0);
			ButtonSetLED(&buttonMap[BTN_F7], 1);
			return;
		case BTN_F8:
			selectedDmxProgram = 8;
			ControllerLoadDMXprogram(selectedDmxProgram);
			ButtonSetFNbuttonLEDS(0);
			ButtonSetLED(&buttonMap[BTN_F8], 1);
			return;

		case BTN_S1:
			selectedDmxInputLock[0] = (selectedDmxInputLock[0]) ? 0 : 1;
			if (selectedDmxInputLock[0])
				ButtonSetLED(&buttonMap[button], 1);
			else
				ButtonSetLED(&buttonMap[button], 0);
			break;
		case BTN_S2:
			selectedDmxInputLock[1] = (selectedDmxInputLock[1]) ? 0 : 1;
			if (selectedDmxInputLock[1])
				ButtonSetLED(&buttonMap[button], 1);
			else
				ButtonSetLED(&buttonMap[button], 0);
			break;
		case BTN_S3:
			selectedDmxInputLock[2] = (selectedDmxInputLock[2]) ? 0 : 1;
			if (selectedDmxInputLock[2])
				ButtonSetLED(&buttonMap[button], 1);
			else
				ButtonSetLED(&buttonMap[button], 0);
			break;
		case BTN_S4:
			selectedDmxInputLock[3] = (selectedDmxInputLock[3]) ? 0 : 1;
			if (selectedDmxInputLock[3])
				ButtonSetLED(&buttonMap[button], 1);
			else
				ButtonSetLED(&buttonMap[button], 0);
			break;
		default:
			break;
		}
	}
	LCDcursorPos(0, 0);
	LCDwrite("Chan Chan Chan Chan ");
	LCDcursorPos(1, 0);

	LCDcursorPos(1, 0);
	const int bufferLen = 21;
	char charBuffer[bufferLen];
	snprintf(charBuffer, bufferLen, " %03d  %03d  %03d  %03d ", selectedDmxChannels[0] + 1, selectedDmxChannels[1] + 1, selectedDmxChannels[2] + 1, selectedDmxChannels[3] + 1);
	LCDwrite(charBuffer);

	LCDcursorPos(2, 0);
	const char * locked = "LOCK";
	const char * open = "OPEN";
	snprintf(charBuffer, bufferLen, "%s %s %s %s ", selectedDmxInputLock[0] ? locked : open, selectedDmxInputLock[1] ? locked : open, selectedDmxInputLock[2] ? locked : open,
			selectedDmxInputLock[3] ? locked : open);
	LCDwrite(charBuffer);

	LCDcursorPos(3, 0);
	snprintf(charBuffer, bufferLen, " %03d  %03d  %03d  %03d ", selectedDmxInputLock[0] ? Dmx512GetChannelValue(selectedDmxChannels[0]) : adcValues[0],
			selectedDmxInputLock[1] ? Dmx512GetChannelValue(selectedDmxChannels[1]) : adcValues[1], selectedDmxInputLock[2] ? Dmx512GetChannelValue(selectedDmxChannels[2]) : adcValues[2],
			selectedDmxInputLock[3] ? Dmx512GetChannelValue(selectedDmxChannels[3]) : adcValues[3]);
	LCDwrite(charBuffer);
}

void ControllerAboutMenu(enum buttonEnum button, int buttonState) {
	LCDcursorPos(0, 0);
	LCDwrite("Daniel Brolin");
	LCDcursorPos(1, 0);
	LCDwrite("David Eriksson");
	LCDcursorPos(2, 0);
	LCDwrite("Johannes Sjolund");
	LCDcursorPos(3, 0);
	LCDwrite("Saman Karimi");
}

void ControllerUSARTpassthrough(enum buttonEnum button, int buttonState) {

}
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

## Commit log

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2017-01-26 Added PCB Folder
    Added Custom library folder, Custom footprints folder, first schematic
    of button PCB.
    [Buttons_PCB.kicad_pcb, Buttons_PCB.sch]
2017-01-26 Added .lib slider and slider project
    stuff
    [Buttons_PCB.kicad_pcb, Buttons_PCB.sch, Sliders_PCB.kicad_pcb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]
2017-01-27 Slider .sch .net .brd added
    Sliders now included in project. Custom footprints and symbols for
    PTA6043 (sliders) fixed.
    Board view not finished, minor design decisions left.
    [Sliders_PCB.kicad_pcb]
2017-01-28 Simple UART echo server
2017-01-30 Buttons PCB almost done
    * Footprints for Cherry MX switches added
    * Buttons.sch edited to finished schematic
    * Buttons.net generated
    * Buttons.kicad_pcb created and designed
    * Uneccesary files deleted
    [Buttons_PCB.kicad_pcb, Buttons_PCB.sch]
2017-01-31 Buttons_PWB_1.0
    First edition Buttons_PWB routed (V1.0).
    [Buttons_PCB.kicad_pcb, Buttons_PCB.sch]
2017-02-01 Buttons_PCB v2
    Changed order of buttons 5-8 to prevent vias below SMD extenders.
    [Buttons_PCB.kicad_pcb]
2017-02-01 PTA6043, Sliders_PCB
    Added:
    PTA 6043 .lib and .pretty
    Drew traces to Sliders_PCB (v1)
    [Sliders_PCB.kicad_pcb, Sliders_PCB.sch]
2017-02-02 Sliders v2
    Sliders_PCB klara
    [Sliders_PCB.kicad_pcb, Sliders_PCB.sch]
2017-02-10 Main board schematic
    [Lab1.kicad_pcb, Lab1.sch]
2017-02-11 Buttons_V3, Sliders_V2
    Easier to manufacture External PCB designs finalized.
    Uneccesary footprints library added "Connectors" (Could not find the
    regular connector FP, turns out it's the socket-strips)
    [Buttons_PCB.kicad_pcb, Buttons_PCB.sch, Sliders_PCB.kicad_pcb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]
2017-02-12 PCB file created for main board
    Nothing really
    [Lab1.kicad_pcb, Lab1.sch, _Lab1.kicad_pcb]
2017-02-12 Main PCB work in progress...
    [Lab1.kicad_pcb, Lab1.sch]
2017-02-12 First PCB version of main board
    [Buttons_PCB.sch, Lab1.kicad_pcb, Lab1.sch]
2017-02-14 Added 3.3v to FT232RL, use larger power tracks
    [Lab1.kicad_pcb, Lab1.sch]
2017-02-14 Fixed DC DC converter footprint
    [Lab1.kicad_pcb, Lab1.sch]
2017-02-15 Rerouted MCU pins for better Nucleo compatibility
    [Lab1.kicad_pcb, Lab1.sch]
2017-02-15 Changed rotary encoder interrupt pin
2017-02-15 Buttons V4
    Pulldown changed to pullup in button switch filter.
    Filter to switch completed (changed).
    [Buttons_PCB.kicad_pcb, _0_Buttons_PCB.kicad_pcb, _0_Buttons_PCB.sch]
2017-02-15 Main_PCB V1 Complete
    Minor changes to everything.
    Main_PCB complete with traces and design.
    [Buttons_PCB.kicad_pcb, Buttons_PCB.sch, Lab1.kicad_pcb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]
2017-02-15 Completed OLED_LCD_PCB v1.1
    * Added Mountingholes.
    * Added "Fatpads" for vias (were on some but not all earlier)
    * Added bottom ground (Or etching will be a bitch)
    * Added Edge cuts (105x65mm)
    [OLED_LCD.kicad_pcb, OLED_LCD.sch]
2017-02-16 USART2 DMA fix
2017-02-16 Working analog to digital project (true studio project) for sliders
    Working analog to digital project (true studio project) for the voltage readings for the analog sliders
2017-02-16 Completed all Circuits for evaluation
    * All board-to-board connectors now Multicomp 02X05
    * Mounting holes for all PCB
    * Vias at all groundpins
    * Minor other changes
    [Buttons_PCB.kicad_pcb, Buttons_PCB.sch, Lab1.kicad_pcb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]
2017-02-18 Working ADC with 4 Channel input in Injected Mode
    Working ADC with 4 Channel input in Injected Mode
    Pins PC0, PC1, PC2, PC3
2017-02-18 Edited Main_PCB from feedback.
    * Added RC-filter (1Mohm, 100nF)
    Little cramped now, but whatever.
    * Filled out groundplanes a little
    [Lab1.kicad_pcb, Lab1.sch]
2017-02-19 DMX512 output almost works. Can read USB->UART from Putty.
2017-02-19 USB usart now works with DMA mode
2017-02-19 Update STM32Cube file with DMA settings
2017-02-19 I2C peripherals use DMA (code generation)
2017-02-19 Minor STM32Cube file fix
    [dmx512-controller-board.ioc]
2017-02-20 Added pullups for EEPROM and button I/Os
    [Lab1.kicad_pcb, Lab1.sch]
2017-02-20 WIP: EEPROM use DMA
2017-02-20 Buttons wrong IO expander footprint fixed
    [Buttons_PCB.kicad_pcb, Buttons_PCB.sch]
2017-02-20 EEPROM, USB USART and DMX now work correctly using DMA
    [dmx512.c, eeprom.c, main.c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]
2017-02-23 Integrated ADC code. Set DMX channel values from ADC.
2017-02-24 Fixed eeprom interrupt bug
    [eeprom.c]
2017-02-25 Removed DMA pause/resume to avoid deadlock in DMX
    [dmx512.c]
2017-02-25 Added Nucleo64 connector image
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2017-02-27 LCD Reset -> 5V
    [OLED_LCD.kicad_pcb, OLED_LCD.sch]
2017-02-27 Oled and photomasks
    * Added 1k Serie resistance to backlight in Oled LCD.
    * Created the photomasks for Buttons and Sliders.
    [Buttons_PCB.kicad_pcb, OLED_LCD.kicad_pcb, OLED_LCD.sch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]
2017-02-28 Started on buttons I/O expander
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2017-03-01 Nya Photomasks Buttons
    [Buttons_PCB.kicad_pcb]
2017-03-01 Edited Buttons and sliders for manufacturability
    * All vias updated to 1.5 or 2 mm diameter
    * Slight designchanges to get rid of drills close to edges in Buttons
    * New Photomasks printed for Buttons and Sliders
    [Buttons_PCB.kicad_pcb, Sliders_PCB.kicad_pcb, _3_Buttons_PCB.kicad_pcb]
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2017-03-02 Manufacture files added
    * Gerbers created
    * Drillfiles created
    * G-CODE generated (milling information)
    [Buttons_PCB.kicad_pcb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]
2017-03-03 Hotfixes, updates and Photomask
    * Edited small error in component placing (OLED_LCD)
    * Updated all photomasks in light of recent events
    * Generated photomask for OLED_LCD (.pdf)
    * Updated all Gerberfiles (.gbr)
    * Updated all drillfiles, now merging "plated" and unplated TH (.drl)
    * With merge; all Non Plated Through Hole drills deleted (-NPTH.drl)
    * Generated new G-CODE for all PCB (.ngc, .svg)
    [Buttons_PCB.kicad_pcb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]
2017-03-05 Fixed compilation issues and bugs
    [main.c]
2017-03-07 Fixed issues with new EEPROM chip
    [eeprom.c, main.c]
2017-03-09 New stuff
    [Buttons_PCB.kicad_pcb, OLED_LCD.kicad_pcb, OLED_LCD.sch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]
2017-03-12 Some work on button board and rot encoder code
2017-03-13 LCD board trim pot and transistor
    [OLED_LCD.sch]
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2017-03-13 Minor buttons code change, print errors to LCD
    [buttons.c, lcd.h, main.c]
2017-03-13 OLED new layout
    * Added few components to OLED_LCD pcb.
    * Extended PCB layout to make room for all components.
    * Generated new LCD photomasks
    [OLED_LCD.kicad_pcb, OLED_LCD.sch]
2017-03-13 Fix button interrupt freeze bug
    [buttons.c, main.c]
2017-03-13 Minor changes to OLED
    [OLED_LCD.kicad_pcb]
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2017-03-15 Rotary encoder and LCD button works. Some readability improvements.
2017-03-16 DMX works on actual fixtures. Improved UI and button handling.
    [buttons.c, buttons.h, controller.c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]
2017-03-18 Added missing 10k R on OLED board, diodes on Buttons board
    [Buttons_PCB.kicad_pcb, Buttons_PCB.sch, OLED_LCD.kicad_pcb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]

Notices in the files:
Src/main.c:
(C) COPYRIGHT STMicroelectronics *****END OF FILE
